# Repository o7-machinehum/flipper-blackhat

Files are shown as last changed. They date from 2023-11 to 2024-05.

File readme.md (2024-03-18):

# Flipper Blackhat
The Flipper Blackhat is a Flipper addon board that runs Linux. It is primarily used for WiFi testing and hacking.


## Other Resources
- [Operating System](https://github.com/o7-machinehum/flipper-blackhat-os)
- [App](https://github.com/o7-machinehum/flipper-blackhat-app)

## R1 Issues
- Reset button doesn't work
- Spacing between M.2 Connectors WRONG

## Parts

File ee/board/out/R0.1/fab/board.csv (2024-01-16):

Source: | /Users/machinehum/projects/flipper-blackhat/ee/board/board.kicad_sch
Date: | 2024 January 09, Tuesday 15:48:44
Tool: | Eeschema 7.0.7
Generator: | /opt/homebrew/bin/kicad-vault
Component Count: | 54
Ref | Qnty | Value | Footprint | Part Number | Detailed Description | QTD Available | Price (QTD 1) | Price (QTD 10) | Price (QTD 100) | Price (QTD 500) | Price (QTD 1000)
C1, C2, C3, C4, | 4 | 10uF | Capacitor_SMD:C_0603_1608Metric | LMK107BBJ106MALT | 10 µF ±20% 10V Ceramic Capacitor X5R 0603 (1608 Metric) | 3863423 | 0.18 | 0.124 | 0.0584 | 0.04312 | 0.0357
C8, C10, C11, C12, C16, | 5 | 100nF | Capacitor_SMD:C_0603_1608Metric | CC0603KRX7R7BB104 | 0.1 µF ±10% 16V Ceramic Capacitor X7R 0603 (1608 Metric) | 11594404 | 0.1 | 0.042 | 0.0185 | 0.01392 | 0.01094
C9, | 1 | 1nF | Capacitor_SMD:C_0603_1608Metric | CC0603KRX7R7BB102 | 1000 pF ±10% 16V Ceramic Capacitor X7R 0603 (1608 Metric) | 158845 | 0.1 | 0.041 | 0.0183 | 0.01378 | 0.01083
C13, C18, | 2 | 22nF | Capacitor_SMD:C_0603_1608Metric | CC0603KRX7R7BB223 | 0.022 µF ±10% 16V Ceramic Capacitor X7R 0603 (1608 Metric) | 46528 | 0.1 | 0.053 | 0.0237 | 0.01782 | 0.014
C14, C15, | 2 | 18pF | Capacitor_SMD:C_0603_1608Metric | CC0603JPNPO9BN180 | 18 pF ±5% 50V Ceramic Capacitor C0G, NP0 0603 (1608 Metric) | 25871 | 0.1 | 0.035 | 0.0156 | 0.01178 | 0.00925
H1, | 1 | M2.5 Spacer | KiLib:9774025151R | 9774025151R | Round Standoff Threaded M2.5x0.45 Steel 0.098" (2.50mm) | 16948 | 1.27 | 1.217 | 0.979 | 0.01178 | 0.00925
J1, | 1 | Lichee_RV_J3 | KiLib:CONN75_2199230-3 | 2199230-3 | 67 Position Female Connector M.2 (NGFF) Mini Card Gold 0.020" (0.50mm) Black | 10721 | 1.61 | 1.47 | 1.3108 | 1.1732 | 0.00925
J2, | 1 | Lichee_RV_J4 | KiLib:CONN75_2199230-3 | 2199230-3 | 67 Position Female Connector M.2 (NGFF) Mini Card Gold 0.020" (0.50mm) Black | 10721 | 1.61 | 1.47 | 1.3108 | 1.1732 | 0.00925
J3, | 1 | USB_A | Connector_USB:USB_A_Receptacle_GCT_USB1046 | USB1046-GF-0190-L-B-A | USB-A (USB TYPE-A) USB 2.0 Receptacle Connector 4 Position Surface Mount, Through Hole | 0 | 1.61 | 1.47 | 1.3108 | 1.1732 | 0.00925
J4, | 1 | Conn_01x08_Pin | Connector_PinHeader_2.54mm:PinHeader_1x08_P2.54mm_Horizontal | PH1RB-08-UA | Connector Header Through Hole, Right Angle 8 position 0.100" (2.54mm) | 10117 | 0.23 | 0.196 | 0.1505 | 0.12738 | 0.10423
J5, | 1 | Conn_01x10_Pin | Connector_PinHeader_2.54mm:PinHeader_1x10_P2.54mm_Horizontal | PH1RB-10-UA | Connector Header Through Hole, Right Angle 10 position 0.100" (2.54mm) | 3117 | 0.24 | 0.202 | 0.1552 | 0.13132 | 0.10744
J6, | 1 | Conn_Coaxial | Connector_Coaxial:SMA_Amphenol_901-143_Horizontal | 901-143-6RFX | SMA Connector Jack, Female Socket 50 Ohms Through Hole, Right Angle Solder | 7948 | 9.33 | 8.397 | 7.5044 | 6.28748 | 5.55732
J8, | 1 | HR911105A | KiLib:HR911105a | HR911105A
L2, | 1 | 120R@100MHz | Inductor_SMD:L_0805_2012Metric | MMZ2012R121AT000 | 120 Ohms @ 100 MHz 1 Signal Line Ferrite Bead 0805 (2012 Metric) 800mA 120mOhm | 269595 | 0.1 | 0.081 | 0.0461 | 0.0307 | 0.02586
R1, R2, | 2 | 22R | Resistor_SMD:R_0603_1608Metric | RC0603FR-1322RL | 22 Ohms ±1% 0.1W, 1/10W Chip Resistor 0603 (1608 Metric) Moisture Resistant Thick Film | 139305 | 0.1 | 0.019 | 0.0093 | 0.00622 | 0.00532
R3, | 1 | 0R | Resistor_SMD:R_0603_1608Metric | RC0603FR-130RL | 0 Ohms Jumper Chip Resistor 0603 (1608 Metric) Moisture Resistant Thick Film | 24216 | 0.1 | 0.017 | 0.007 | 0.00448 | 0.00329
R5, R6, R7, R8, R9, R10, R11, R21, R30, R32, R33, | 11 | 5.1k | Resistor_SMD:R_0603_1608Metric | RC0603FR-135K1L | 5.1 kOhms ±1% 0.1W, 1/10W Chip Resistor 0603 (1608 Metric) Thick Film | 155768 | 0.1 | 0.019 | 0.0093 | 0.00622 | 0.00532
R13, | 1 | 10k | Resistor_SMD:R_0603_1608Metric | RC0603FR-1310KL | 10 kOhms ±1% 0.1W, 1/10W Chip Resistor 0603 (1608 Metric) Moisture Resistant Thick Film | 152935 | 0.1 | 0.019 | 0.0093 | 0.00622 | 0.00532
R15, | 1 | 100K | Resistor_SMD:R_0603_1608Metric | RC0603FR-13100KL | 100 kOhms ±1% 0.1W, 1/10W Chip Resistor 0603 (1608 Metric) Moisture Resistant Thick Film | 44445 | 0.1 | 0.019 | 0.0093 | 0.00622 | 0.00532
R16, R17, | 2 | 1k | Resistor_SMD:R_0603_1608Metric | RC0603FR-131KL | 1 kOhms ±1% 0.1W, 1/10W Chip Resistor 0603 (1608 Metric) Moisture Resistant Thick Film | 49915 | 0.1 | 0.019 | 0.0093 | 0.00622 | 0.00532
R19, | 1 | 100R | Resistor_SMD:R_0603_1608Metric | RC0603FR-13100KL | 100 kOhms ±1% 0.1W, 1/10W Chip Resistor 0603 (1608 Metric) Moisture Resistant Thick Film | 44445 | 0.1 | 0.019 | 0.0093 | 0.00622 | 0.00532
R31, R34, | 2 | 470R | Resistor_SMD:R_0603_1608Metric | RC0603FR-13470KL | 470 kOhms ±1% 0.1W, 1/10W Chip Resistor 0603 (1608 Metric) Moisture Resistant Thick Film | 80619 | 0.1 | 0.019 | 0.0093 | 0.00622 | 0.00532
RN1, RN2, | 2 | 10k | Resistor_SMD:R_Array_Convex_4x0402 | 4D02WGJ0103TCE
RN5, RN6, RN7, | 3 | 22R | Resistor_SMD:R_Array_Convex_4x0402 | 4D02WGJ0220TCE
SW1, | 1 | SW_Push | Button_Switch_SMD:SW_SPST_PTS645 | PTS645SH43SMTR92 LFS | Tactile Switch SPST-NO Top Actuated Surface Mount | 280362 | 0.28 | 0.275 | 0.2364 | 0.20032 | 0.00532
U1, | 1 | RTL8201F | Package_DFN_QFN:QFN-32-1EP_5x5mm_P0.5mm_EP3.3x3.3mm | RTL8201F
U2, | 1 | RTL8723DS | KiLib:RTL8723 | RTL8723DS
U6, | 1 | USBLC6-2SC6 | Package_TO_SOT_SMD:SOT-23-6 | USBLC6-2SC6 | 17V Clamp 5A (8/20µs) Ipp Tvs Diode Surface Mount SOT-23-6 | 69609 | 0.58 | 0.496 | 0.3448 | 0.2692 | 0.21881
Y1, | 1 | Crystal_GND24_Small | Crystal:Crystal_SMD_3225-4Pin_3.2x2.5mm | 7M25000033

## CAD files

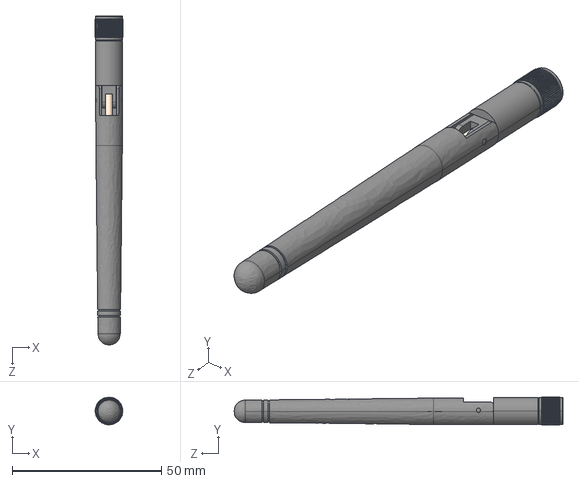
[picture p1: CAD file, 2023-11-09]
ee/board/step/antenna.step
9.33 x 9.33 x 110.2 mm

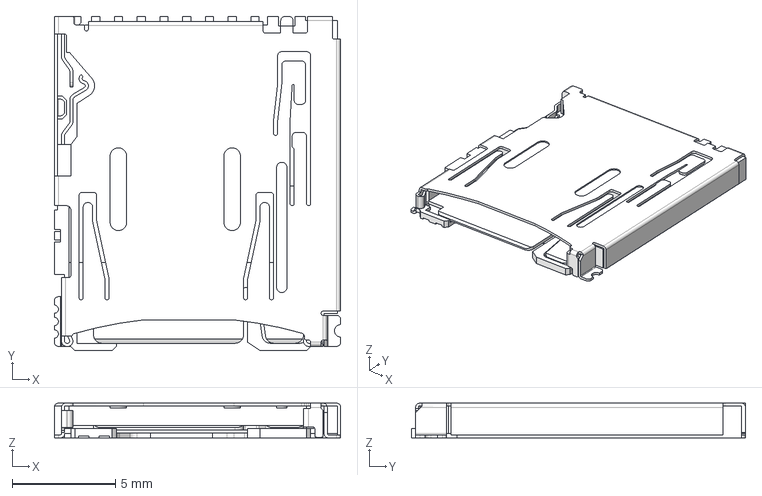
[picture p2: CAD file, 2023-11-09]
ee/board/step/DM3AT-SF-PEJM5.stp
13.8 x 16.2 x 1.68 mm

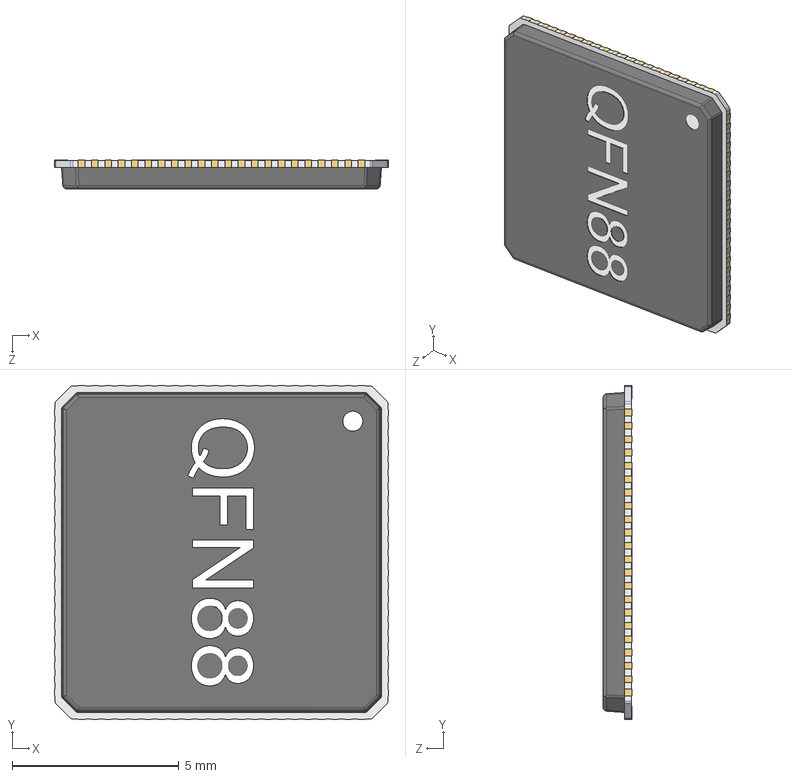
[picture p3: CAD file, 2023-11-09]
ee/board/step/QFN88.stp
10.0 x 10.0 x 0.87 mm

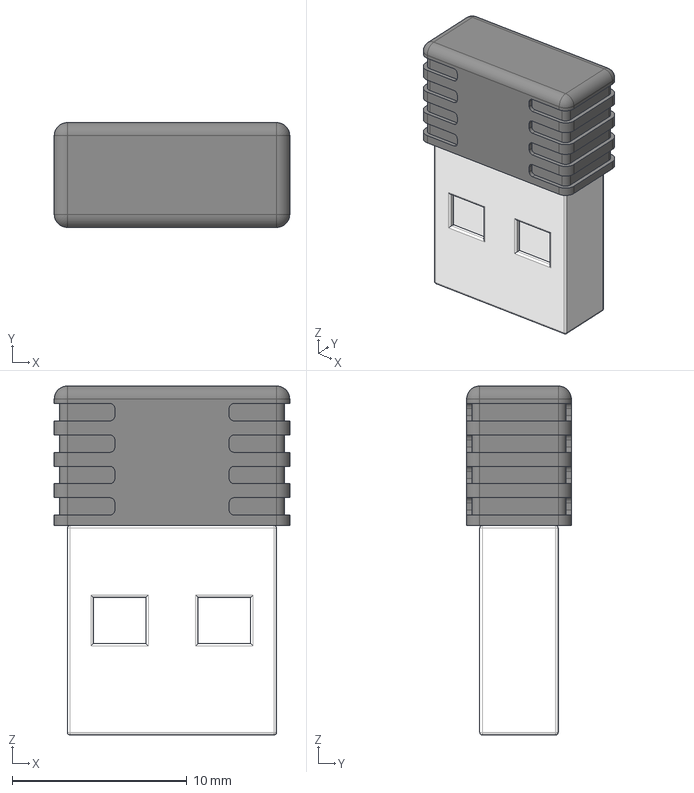
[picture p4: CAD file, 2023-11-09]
ee/board/step/mini_usb_wifi_adapter.stp
13.5 x 6.00 x 20.0 mm

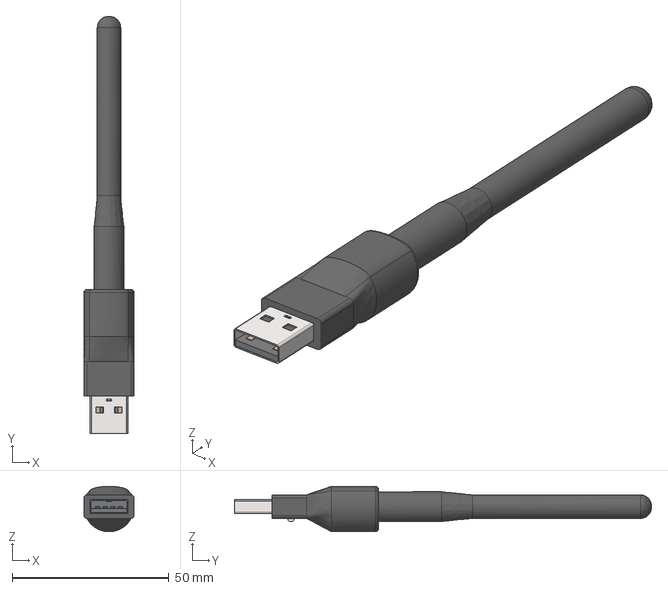
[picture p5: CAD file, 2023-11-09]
ee/board/step/usb-antenna.step
16.0 x 132.9 x 14.5 mm

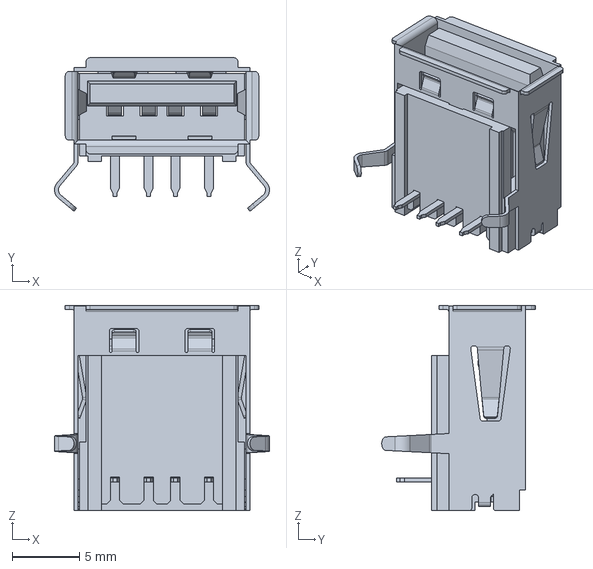
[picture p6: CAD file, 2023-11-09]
ee/board/step/676432911.stp
16.0 x 11.4 x 15.3 mm

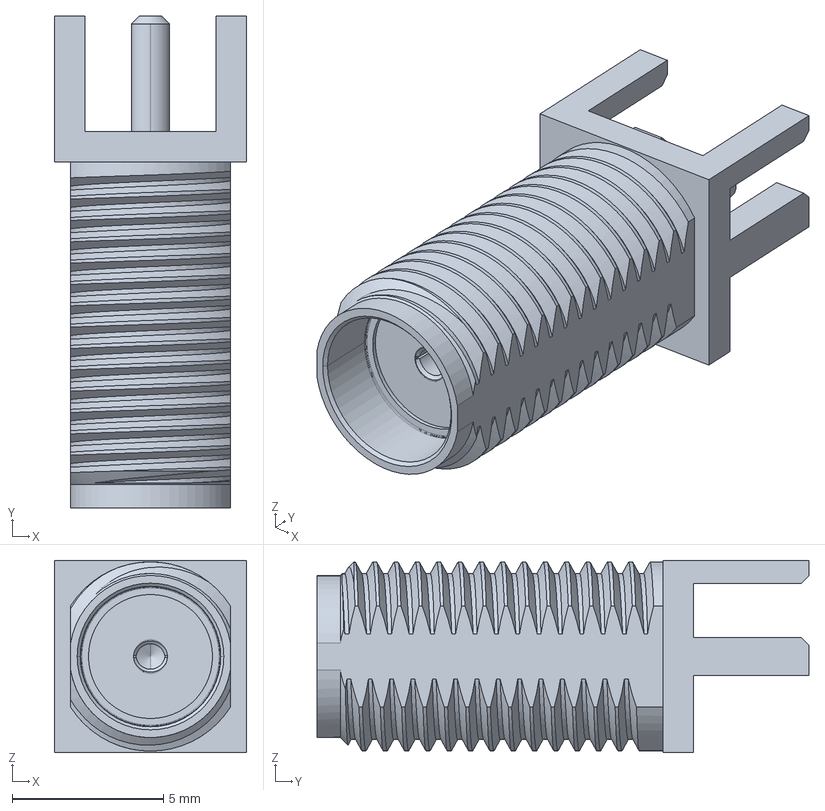
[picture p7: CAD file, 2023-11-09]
ee/board/step/732512120.stp
6.35 x 16.3 x 6.35 mm

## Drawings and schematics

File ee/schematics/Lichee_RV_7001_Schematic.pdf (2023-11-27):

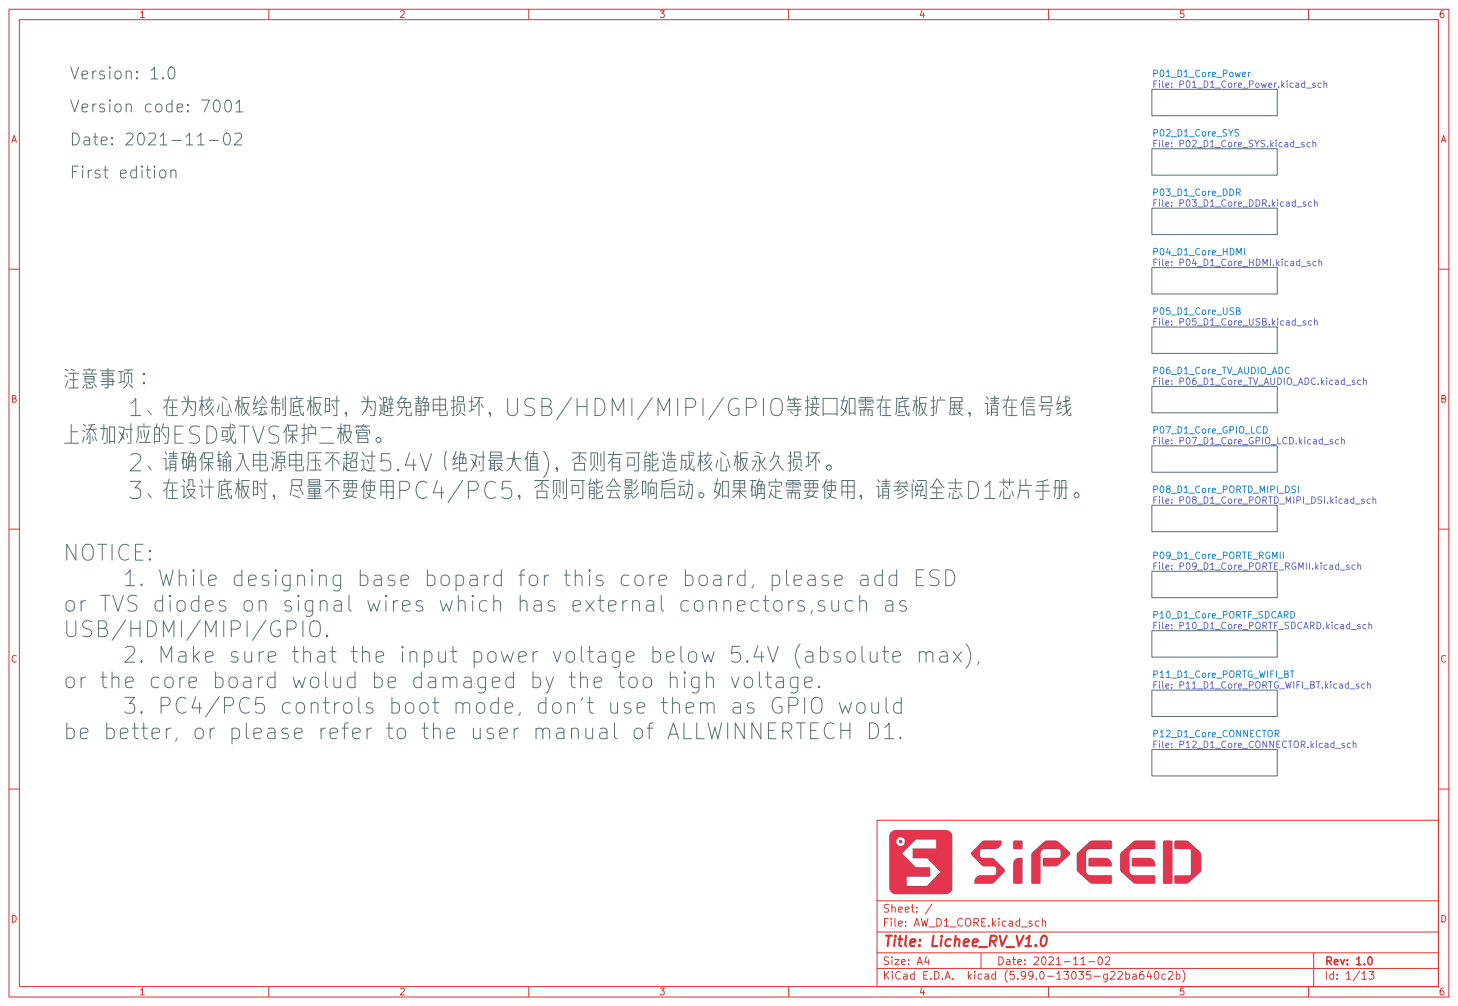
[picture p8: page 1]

þÿlèaN‹˜yÿ
þÿ 10W(N:h8_Ãg•~ØR6^•g•eöÿN:••QM—Yu5c_WOÿUSB/HDMI/MIPI/GPIO{Ic¥SãY‚—W(^•g•bi\Uÿ‹÷W(OáS÷~¿
þÿN
þÿ 20‹÷xnOÝ•“Qeu5n•u5S‹N
þÿ 30W(‹¾‹¡^•g•eöÿ\=‘ÏN

mûR [ù^”v„ESDbTVSOÝb¤NŒg•{¡0-

File: P12_D1_Core_CONNECTOR.kicad_sch NOTICE:
1. While designing base bopard for this core board, please add ESD
or TVS diodes on signal wires which has external connectors,such as
USB/HDMI/MIPI/GPIO.
2. Make sure that the input power voltage below 5.4V (absolute max),
or the core board wolud be damaged by the too high voltage.
3. PC4/PC5 controls boot mode, don't use them as GPIO would
be better, or please refer to the user manual of ALLWINNERTECH D1.

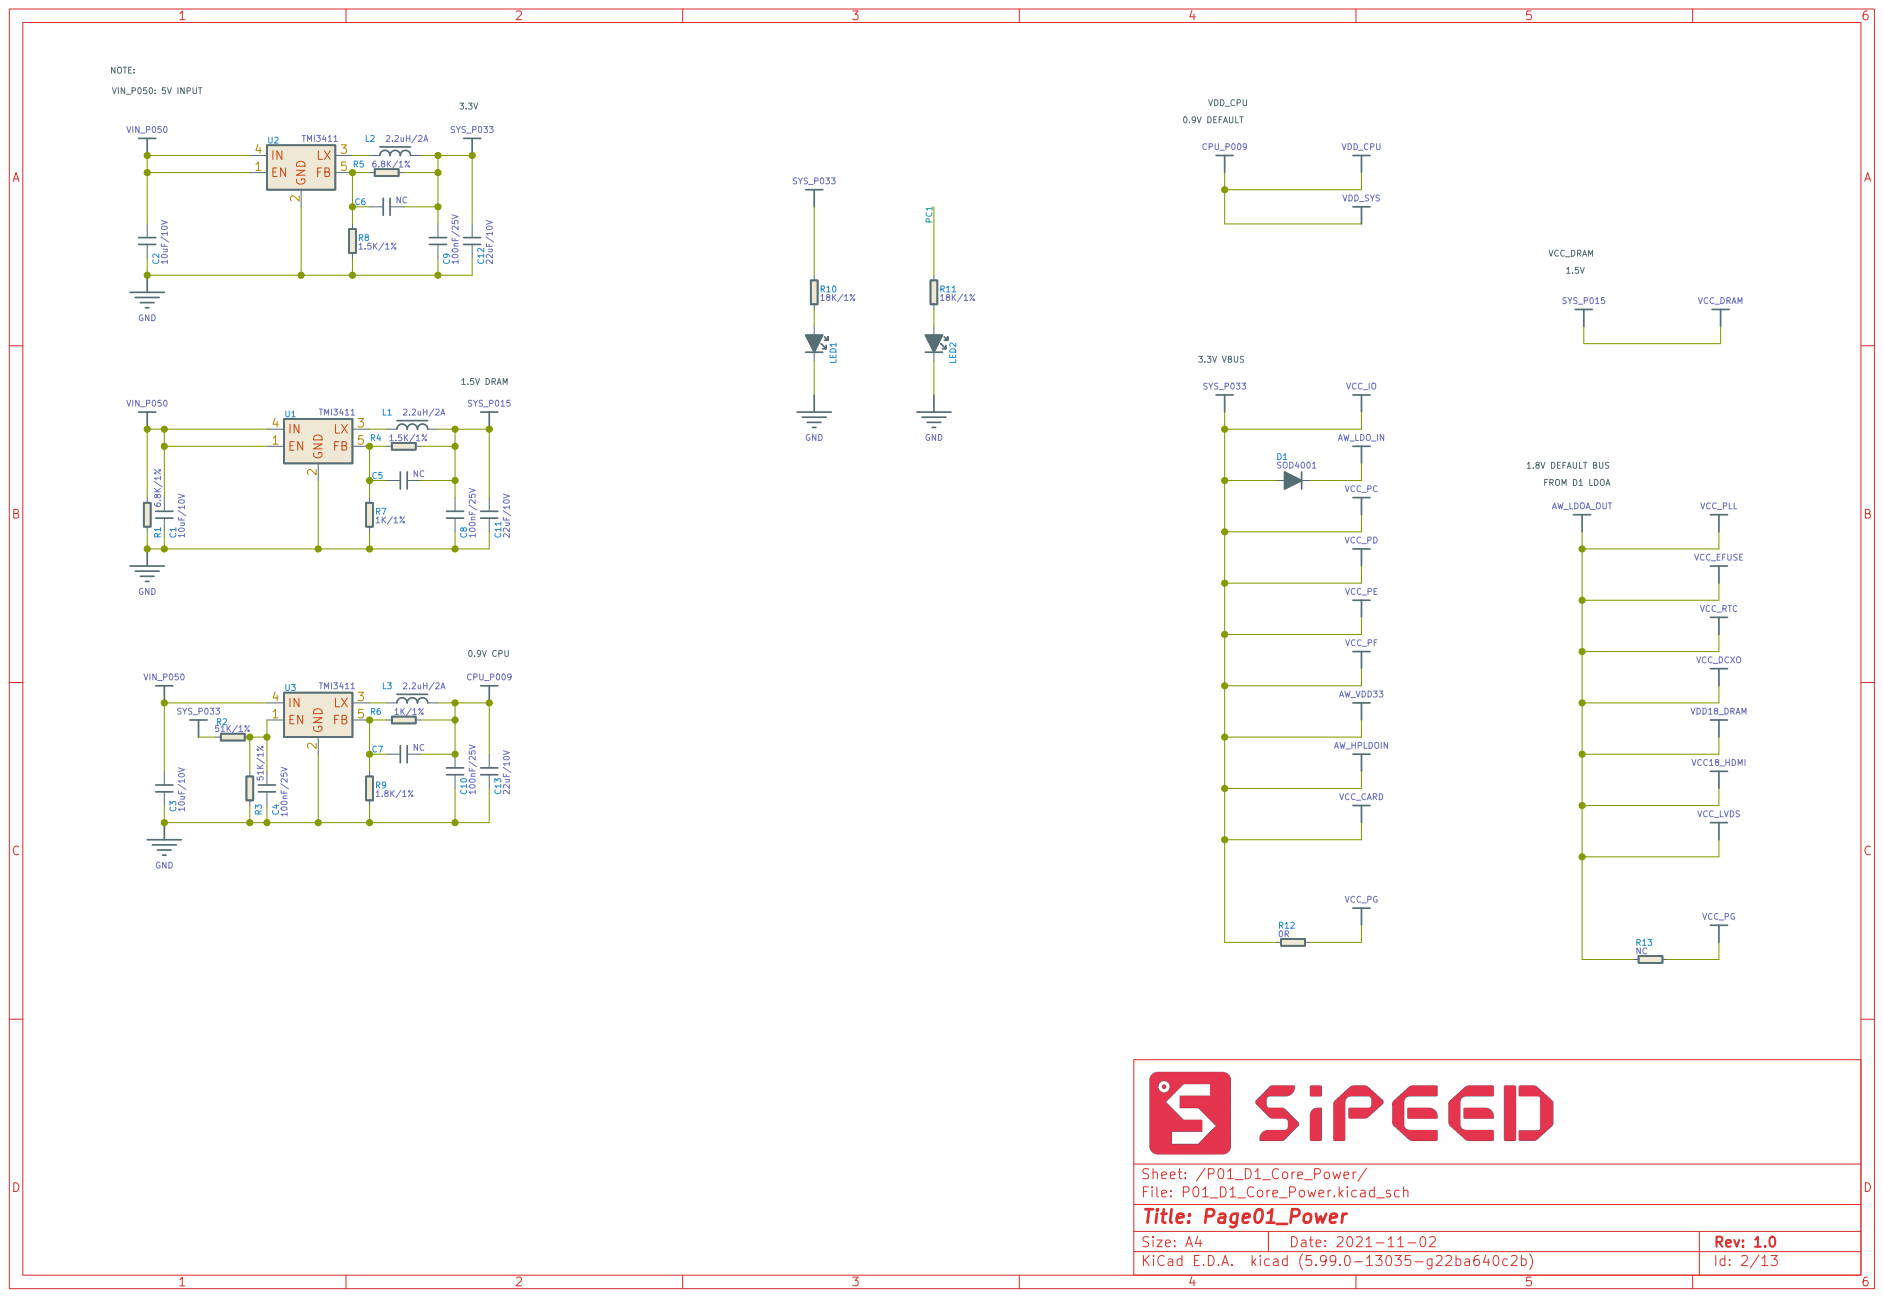
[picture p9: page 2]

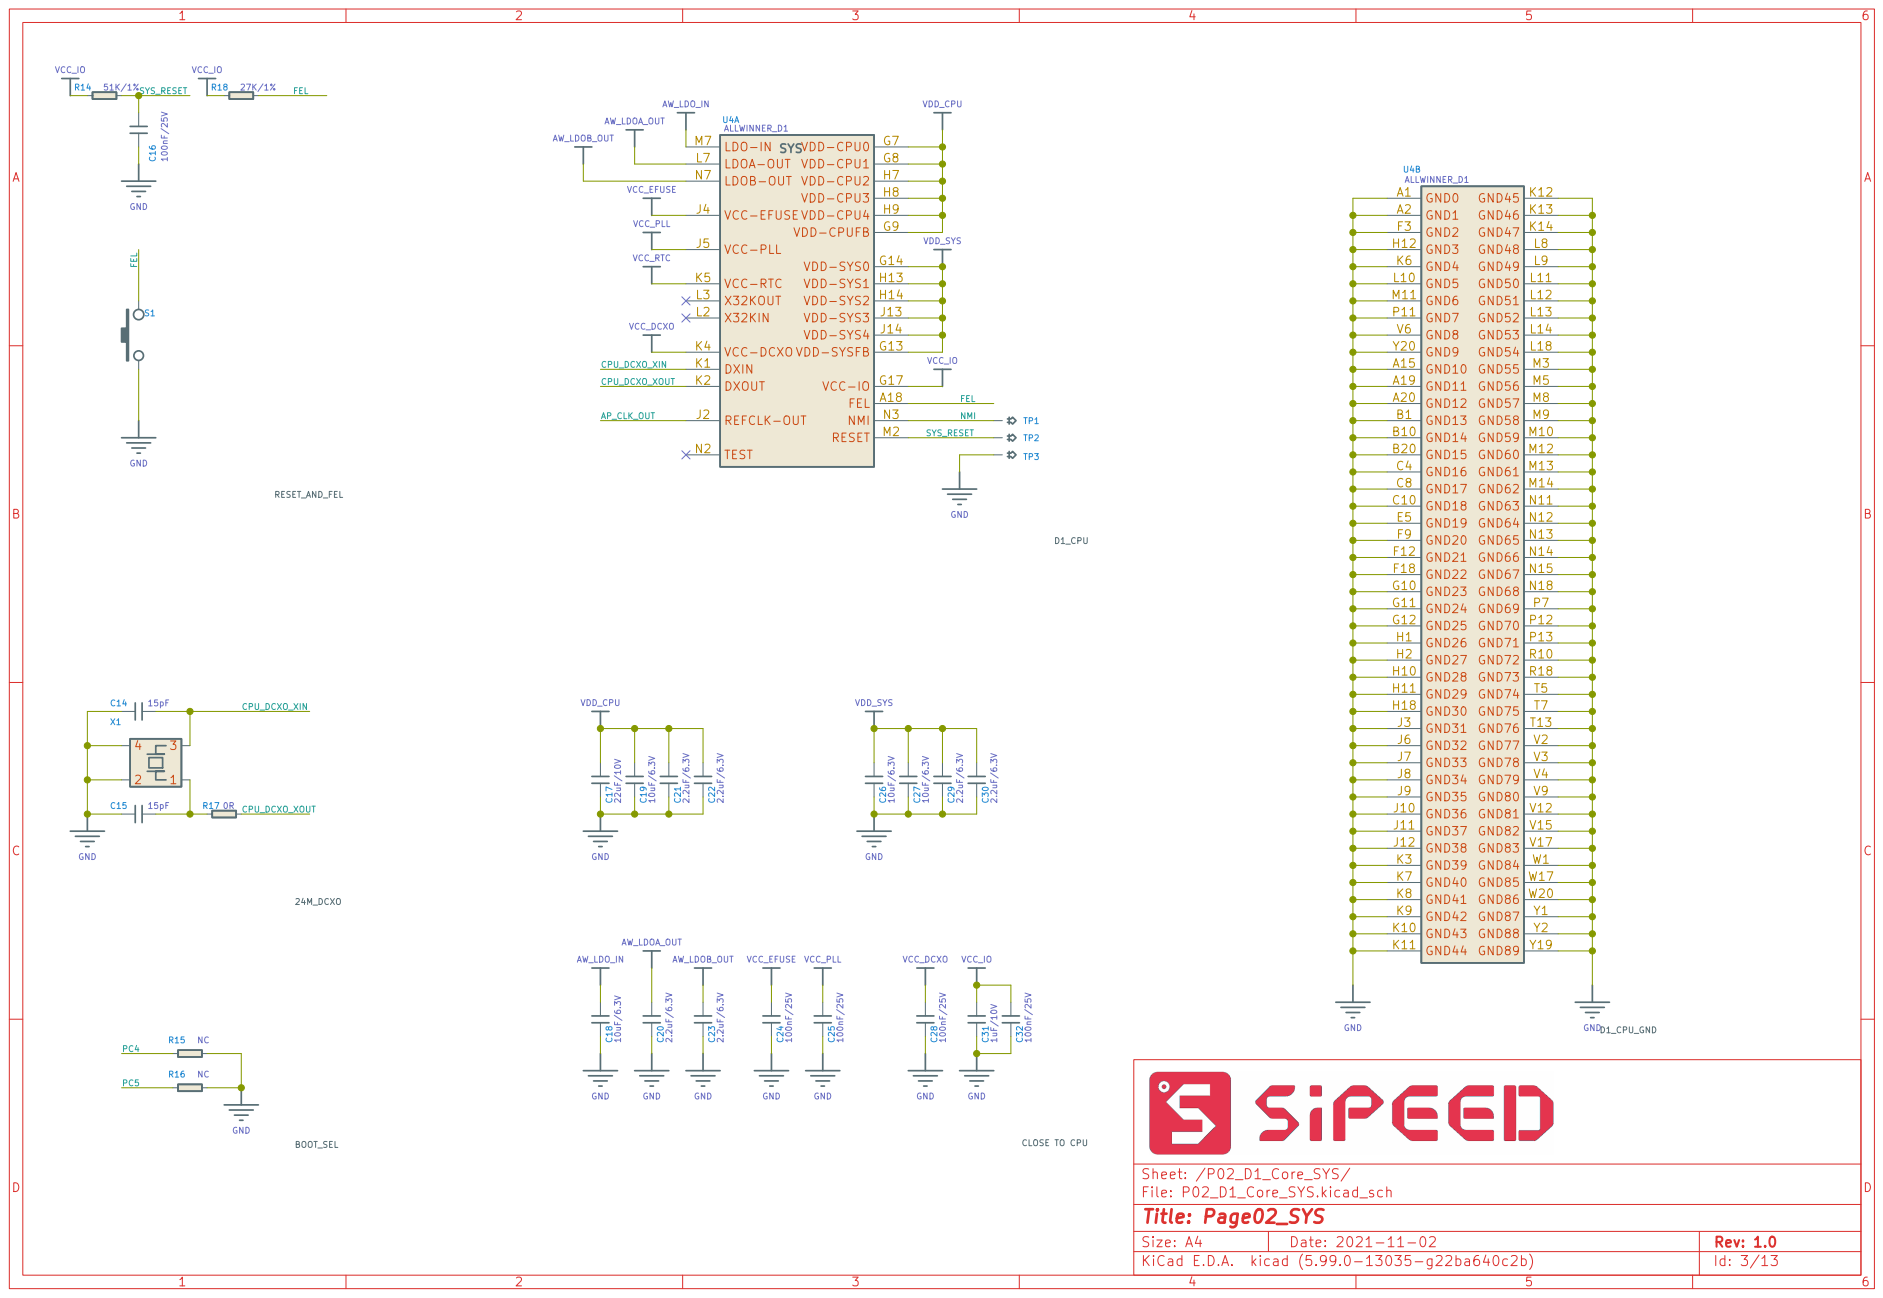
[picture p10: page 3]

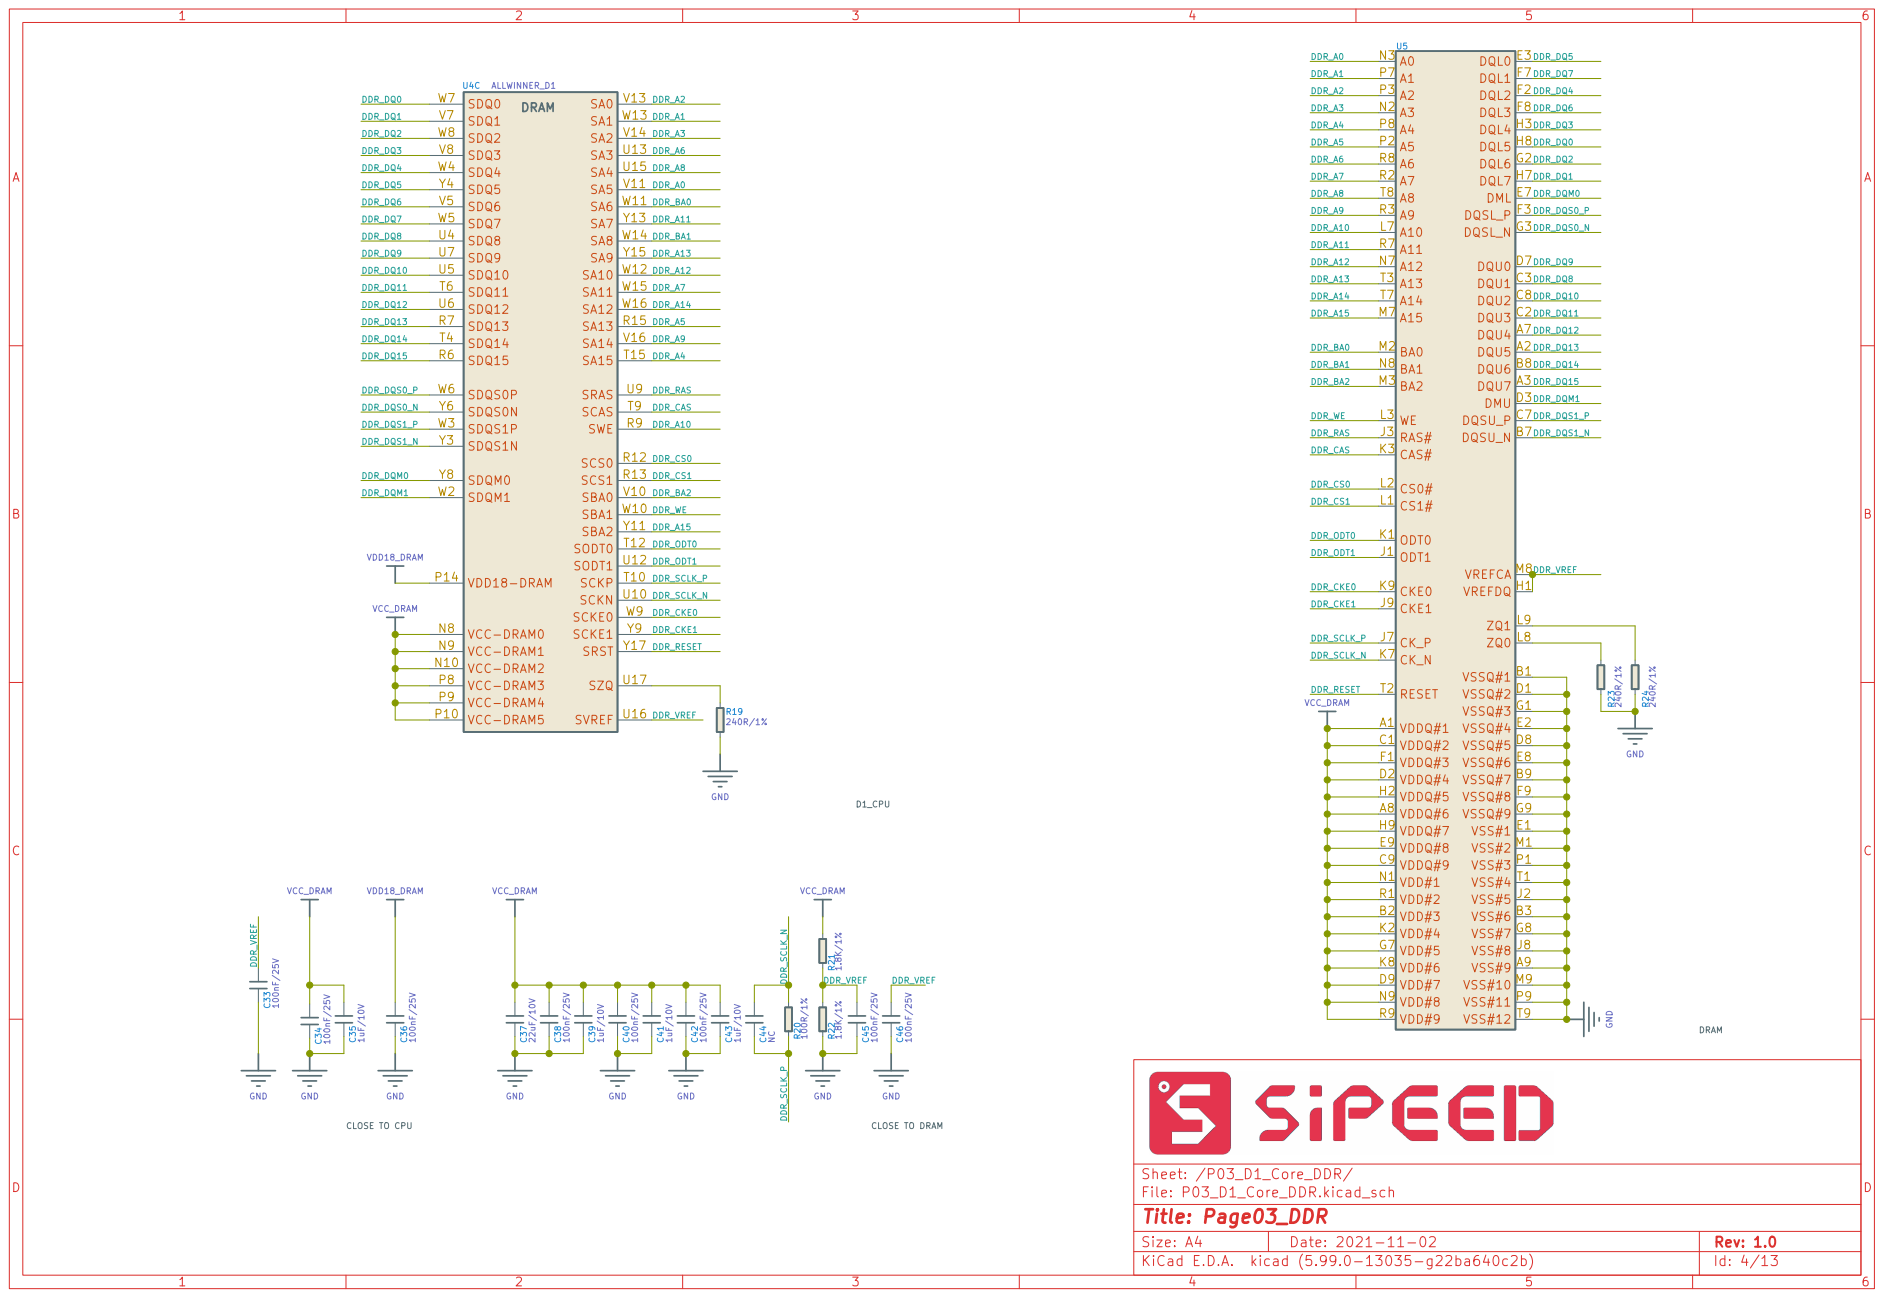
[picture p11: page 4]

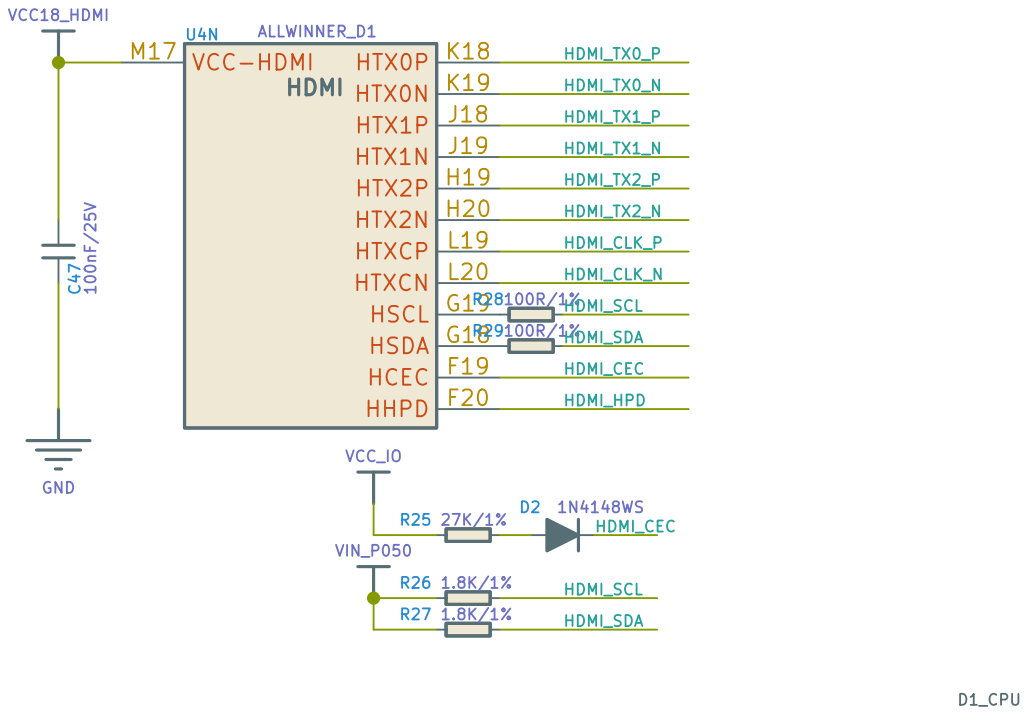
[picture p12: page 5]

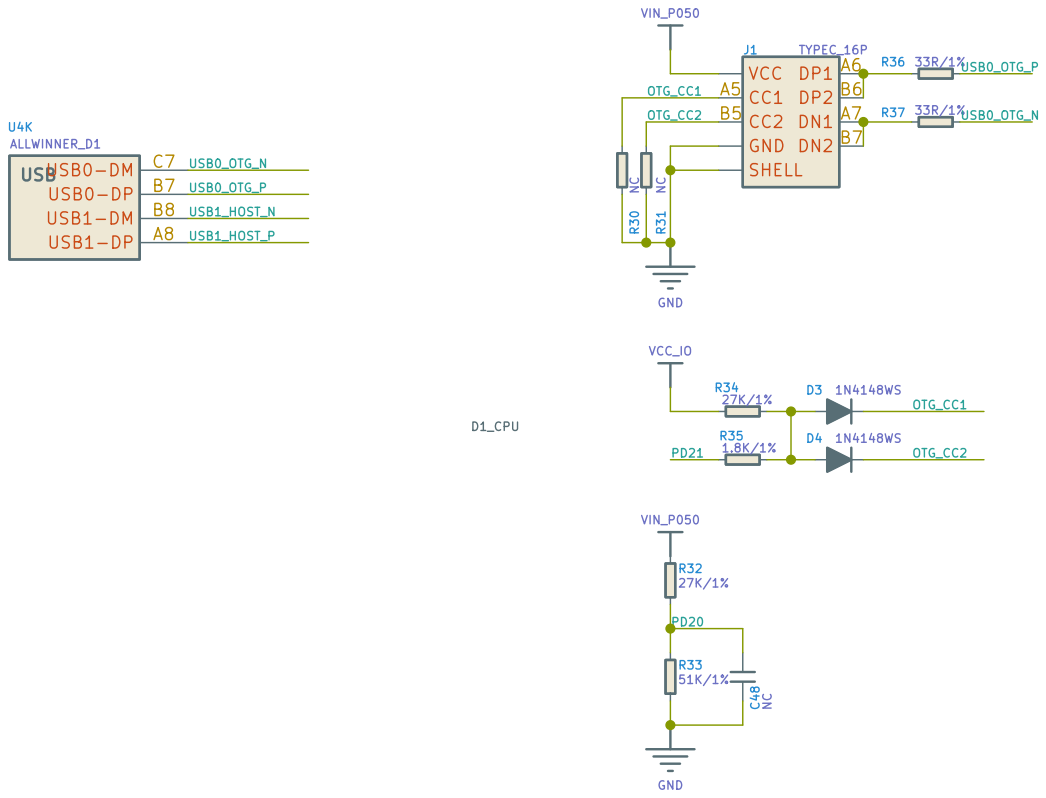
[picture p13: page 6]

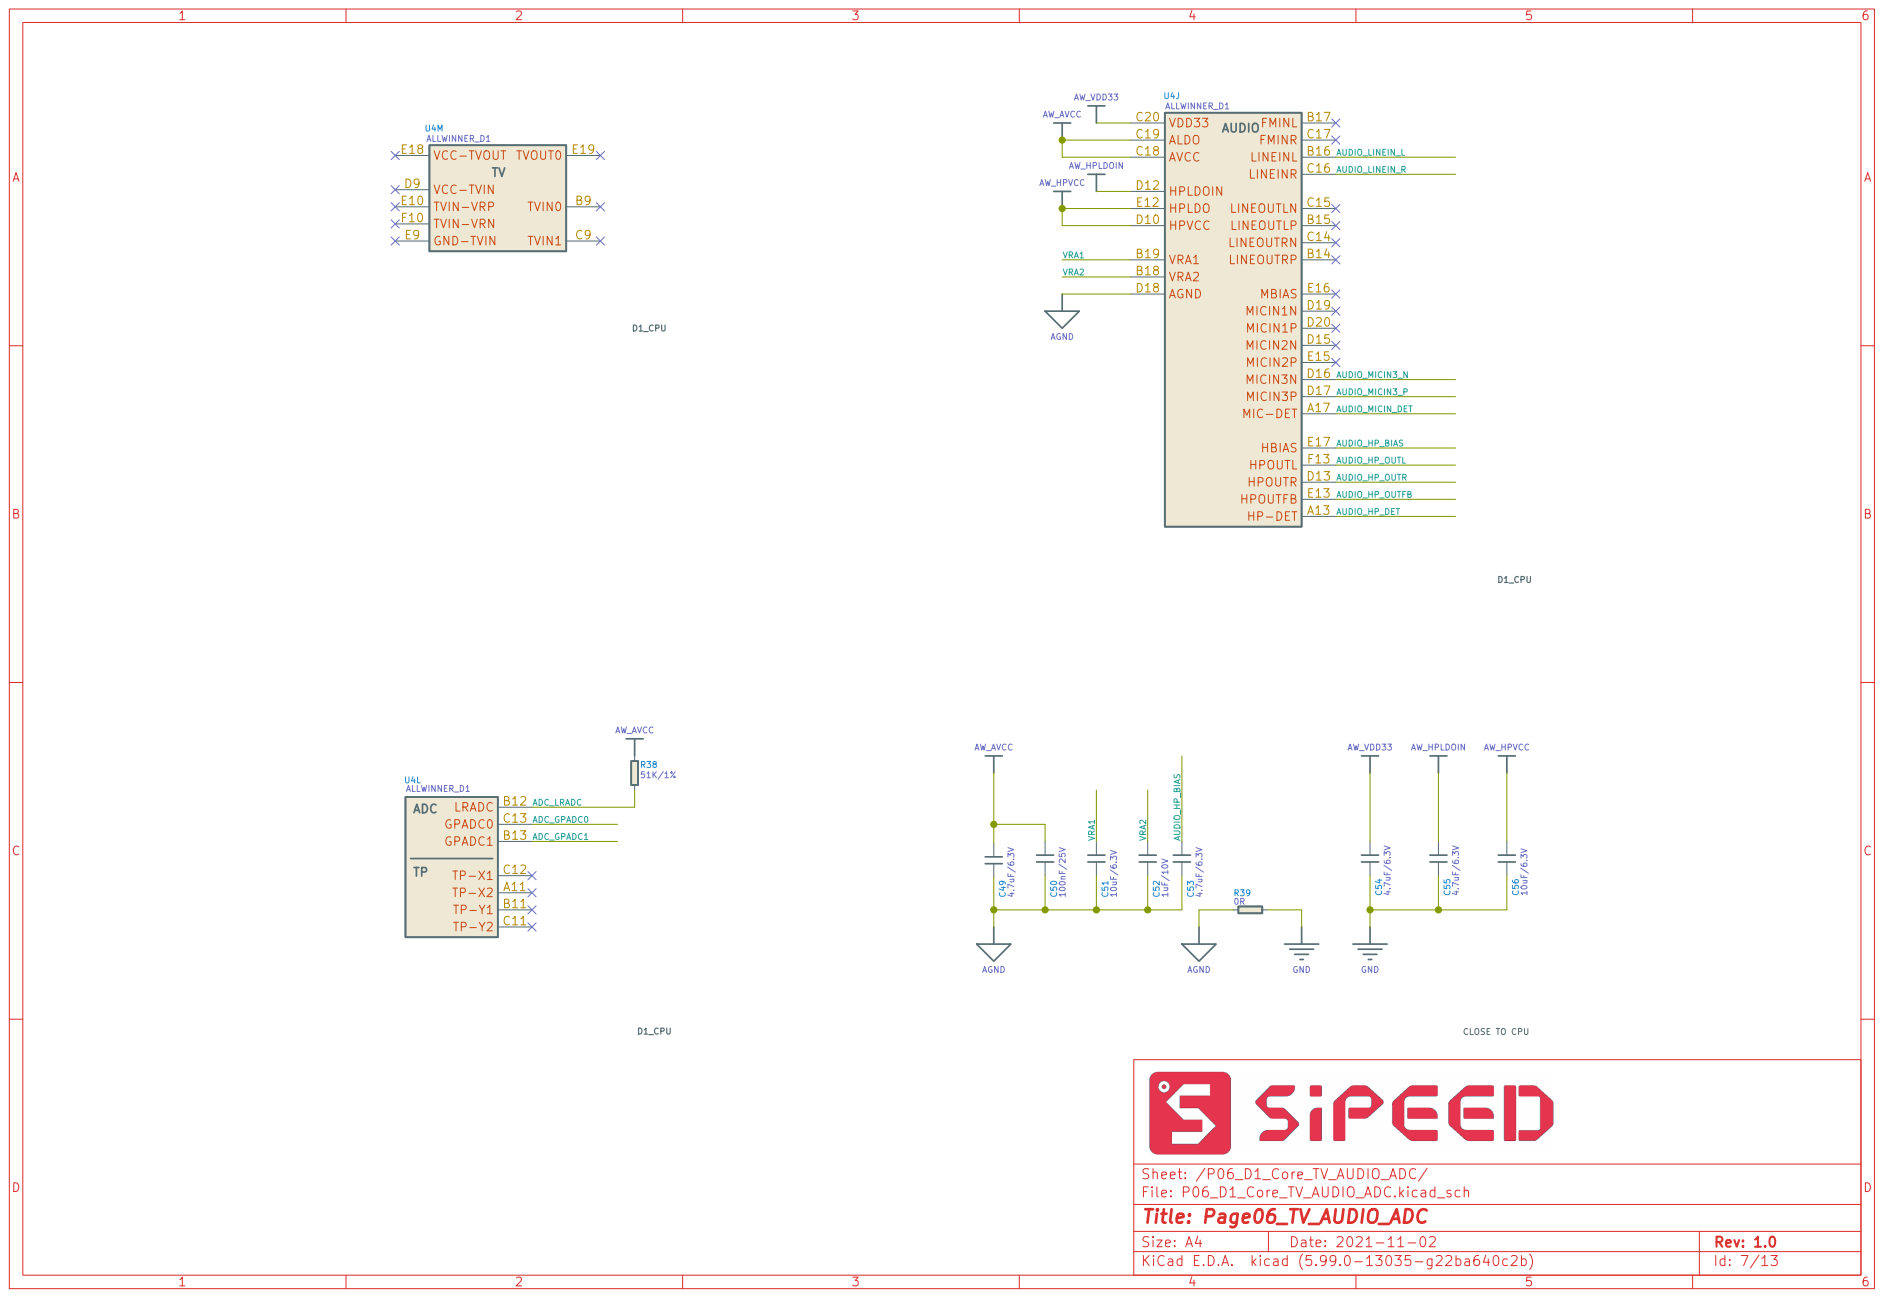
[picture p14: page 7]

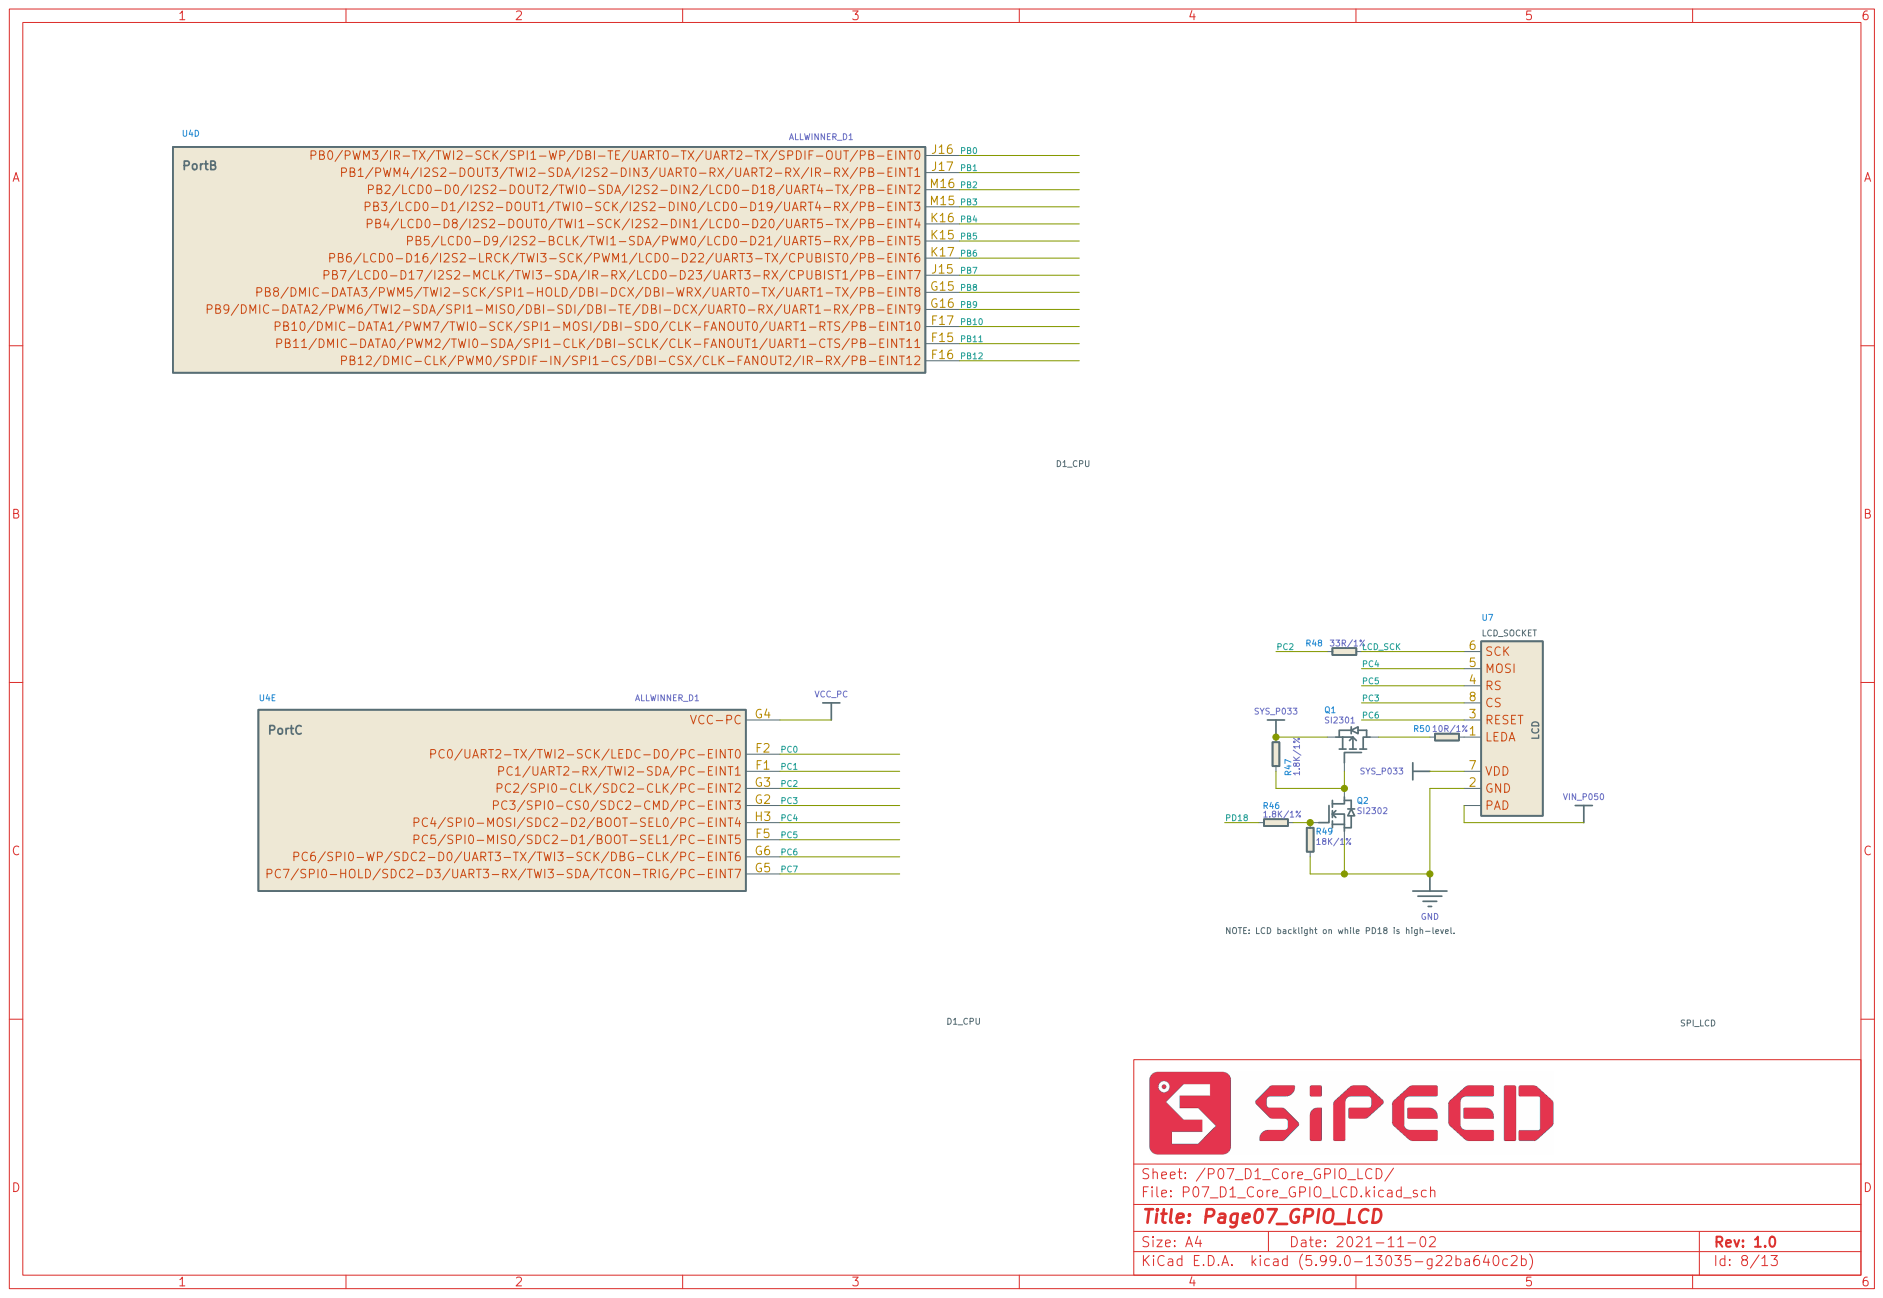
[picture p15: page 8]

NOTE: LCD backlight on while PD18 is high-level.

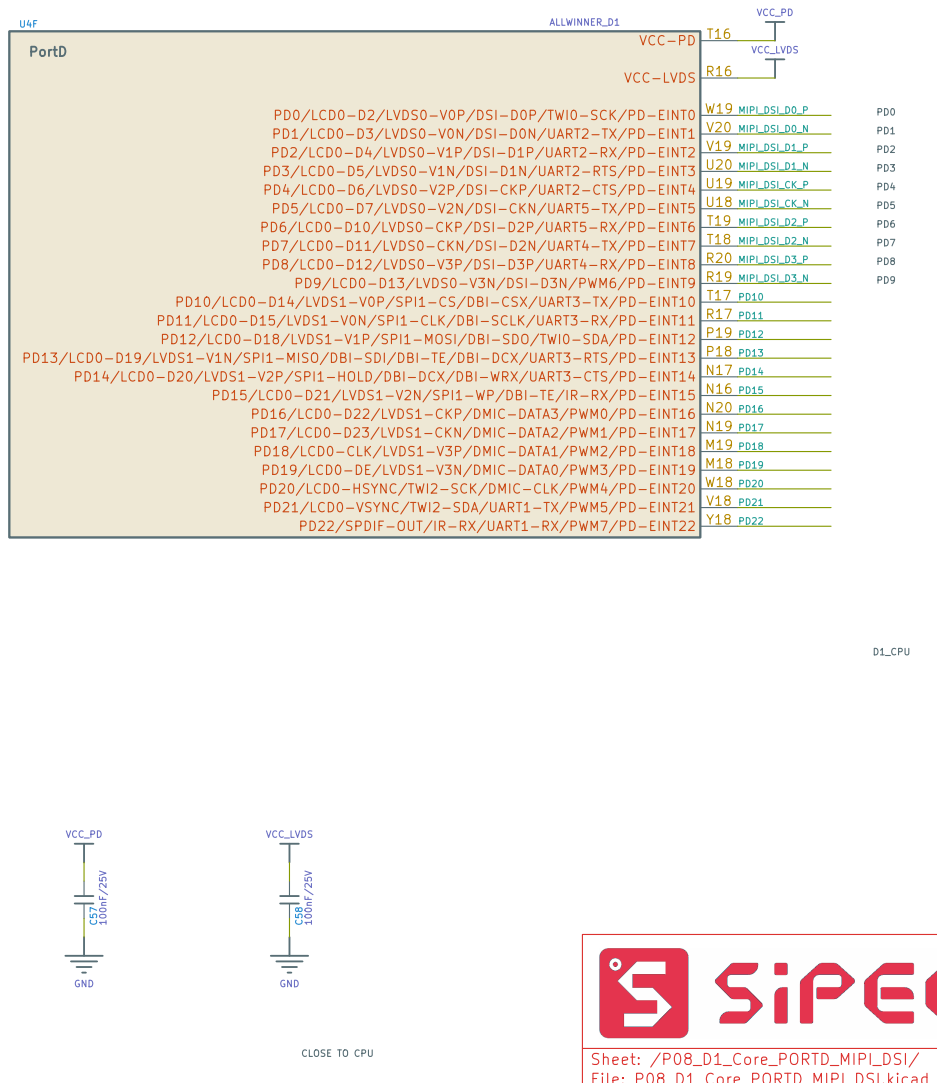
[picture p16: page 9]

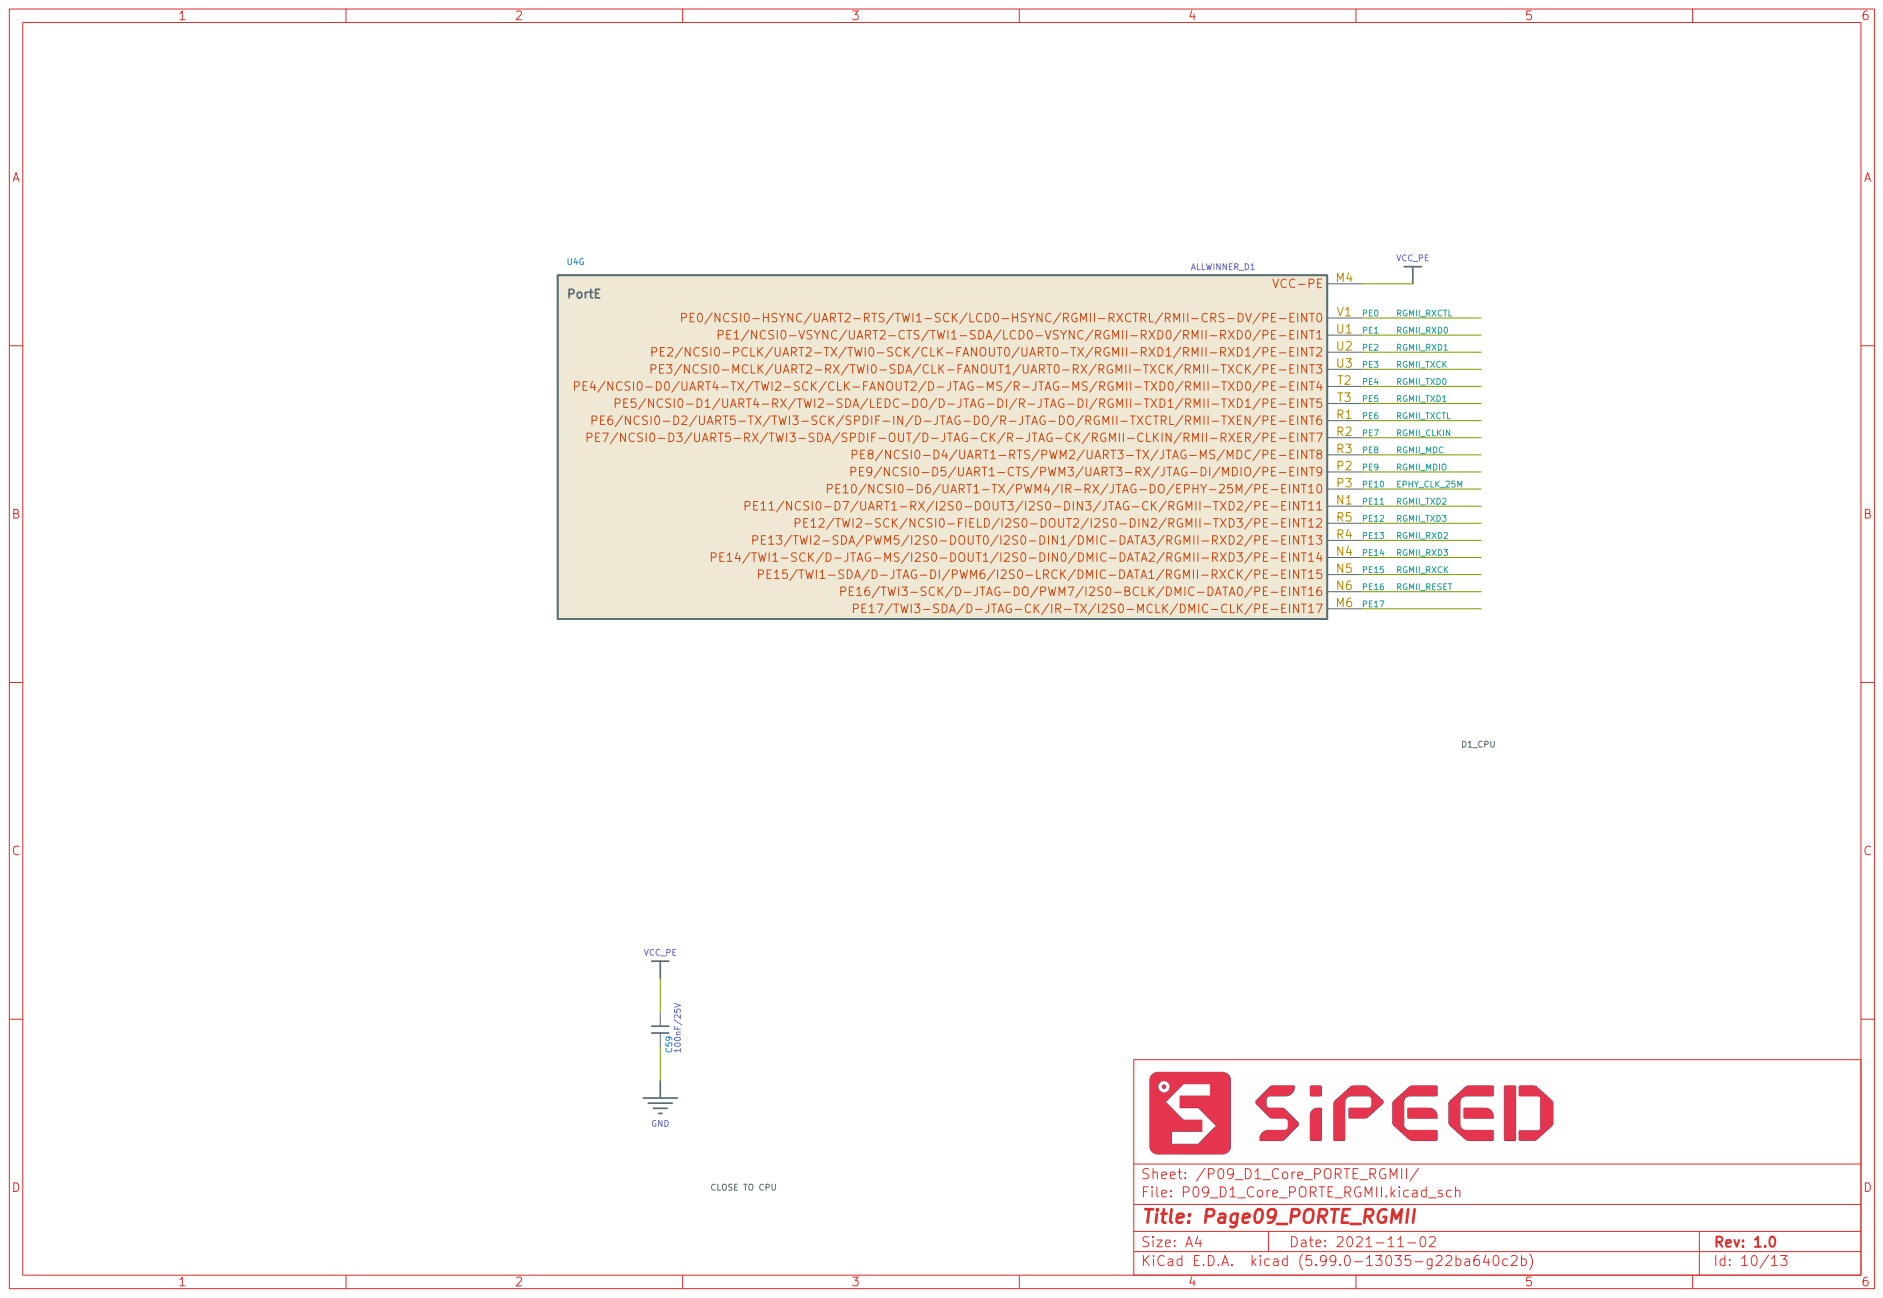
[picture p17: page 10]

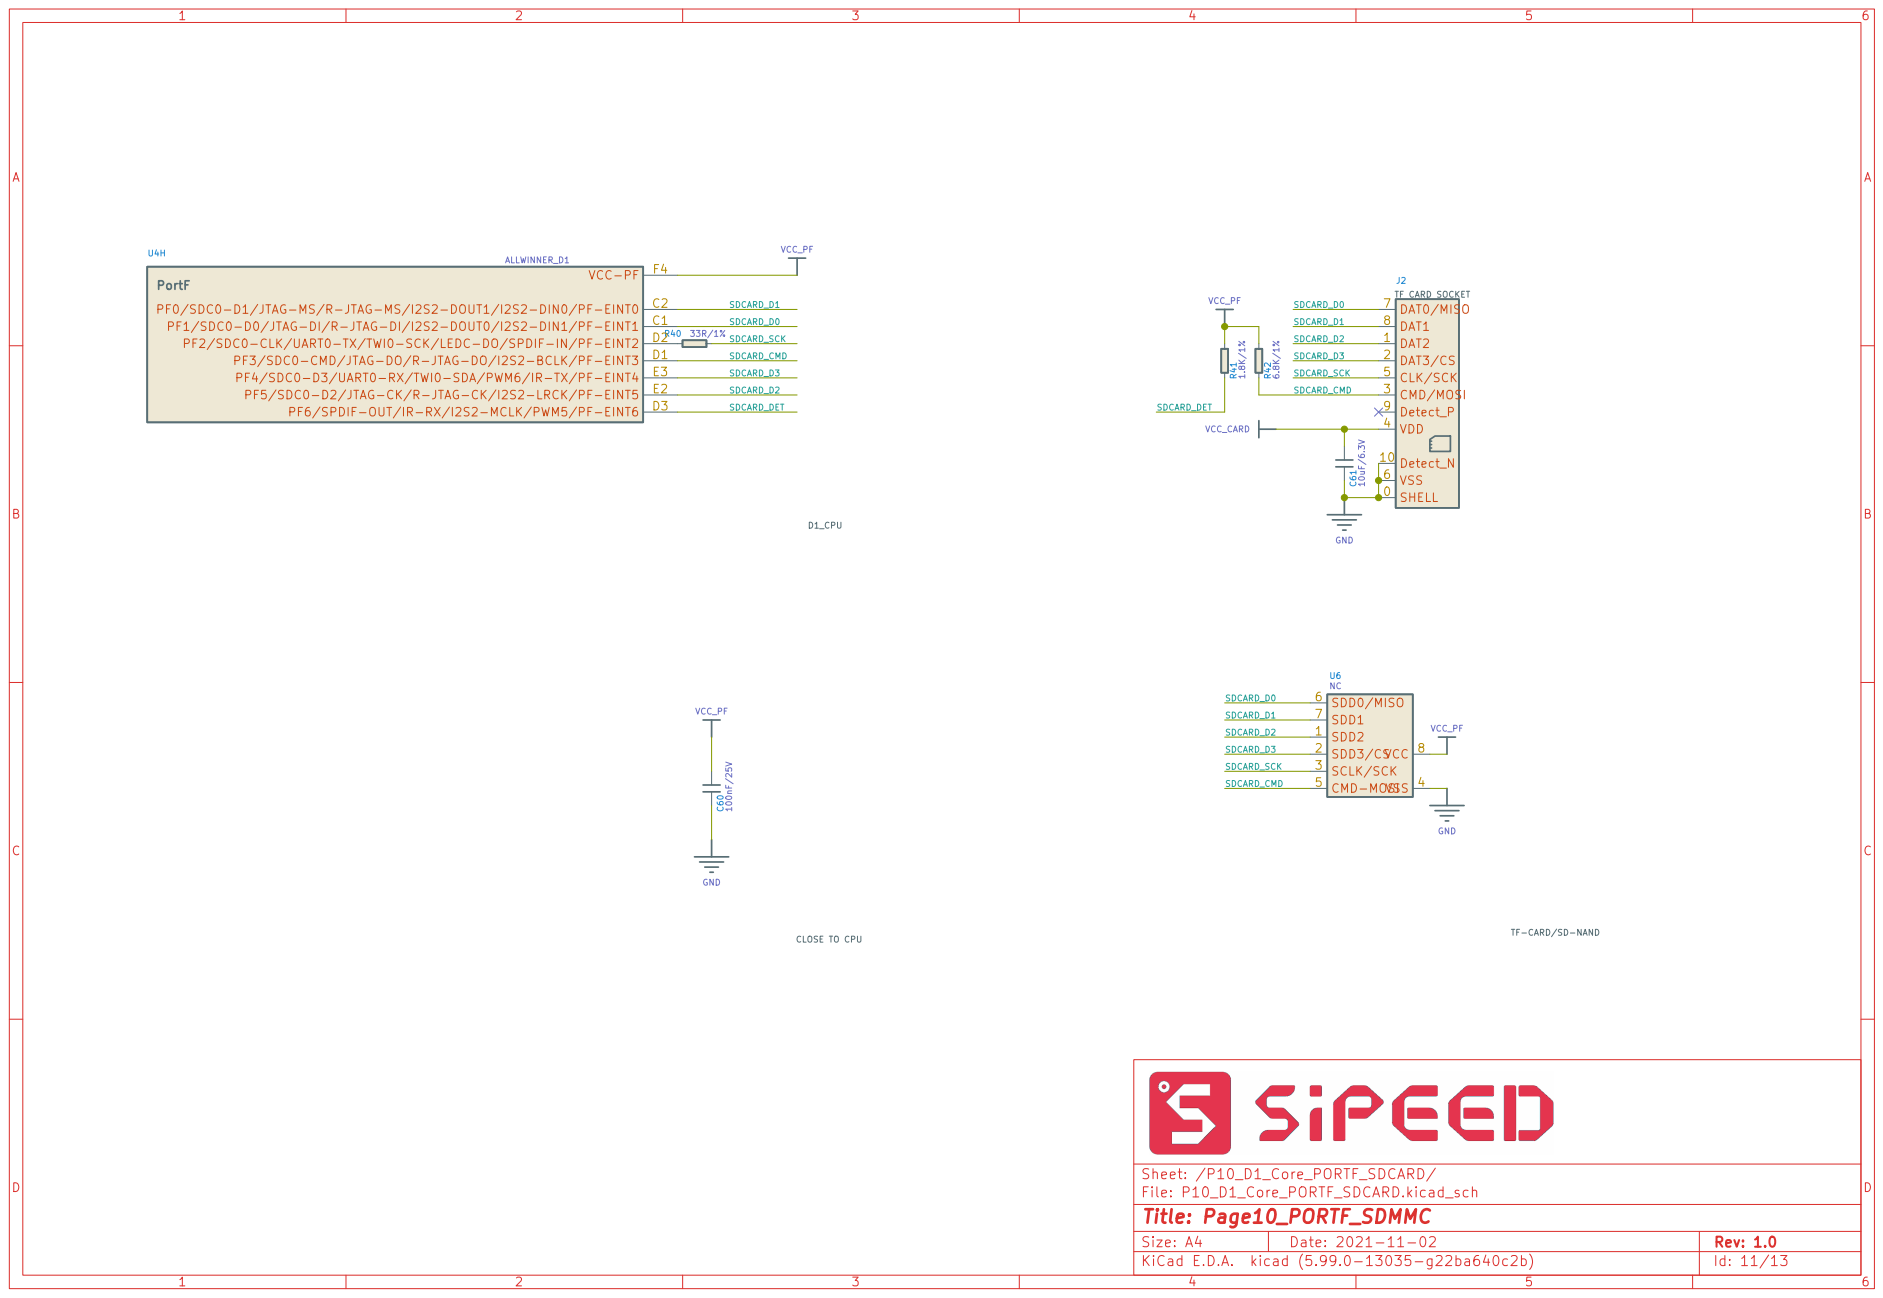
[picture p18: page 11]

TF-CARD/SD-NAND

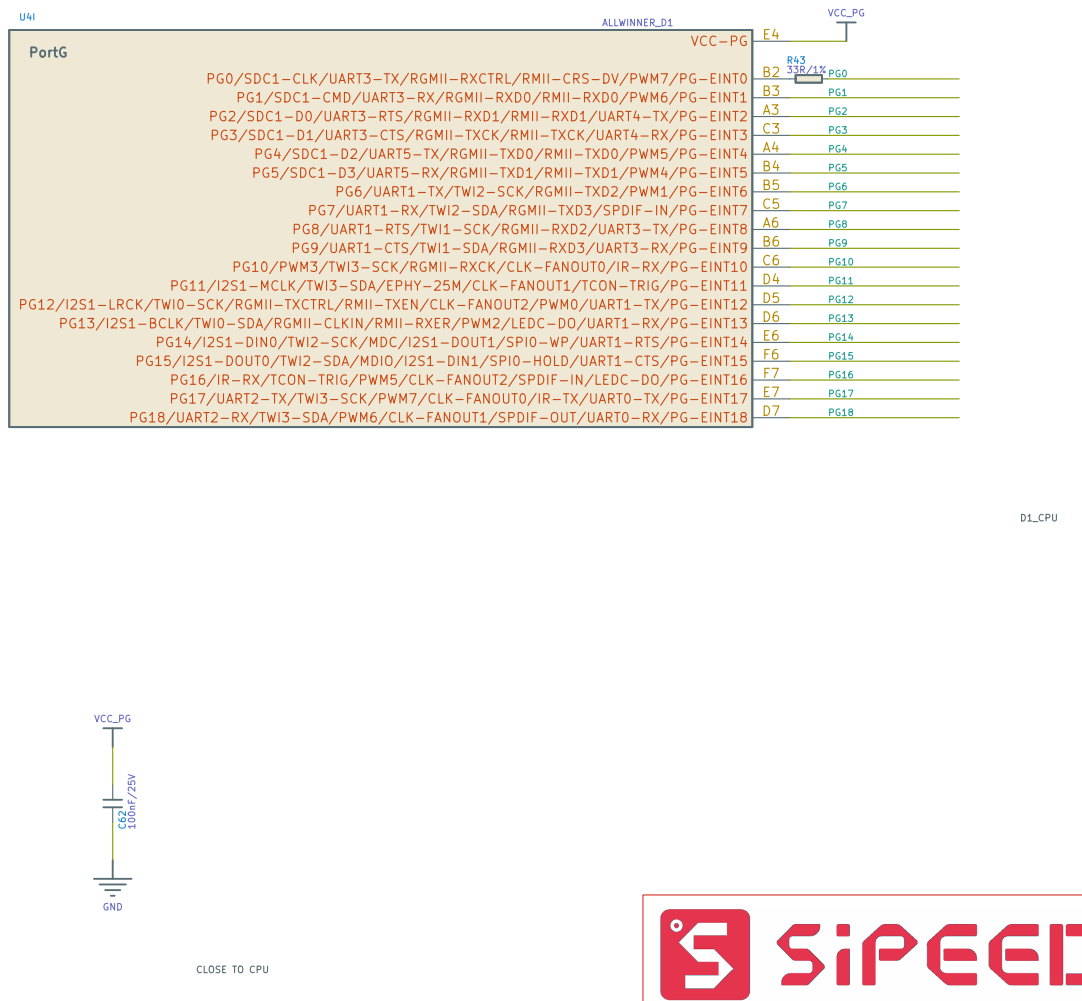
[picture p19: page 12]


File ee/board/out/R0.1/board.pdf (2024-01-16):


Id: 1/2 Title: Flipper Blackhat File: board.kicad_sch Sheet: /


Id: 2/2 Title: Flipper Blackhat File: ethernet.kicad_sch Sheet: /Ethernet/

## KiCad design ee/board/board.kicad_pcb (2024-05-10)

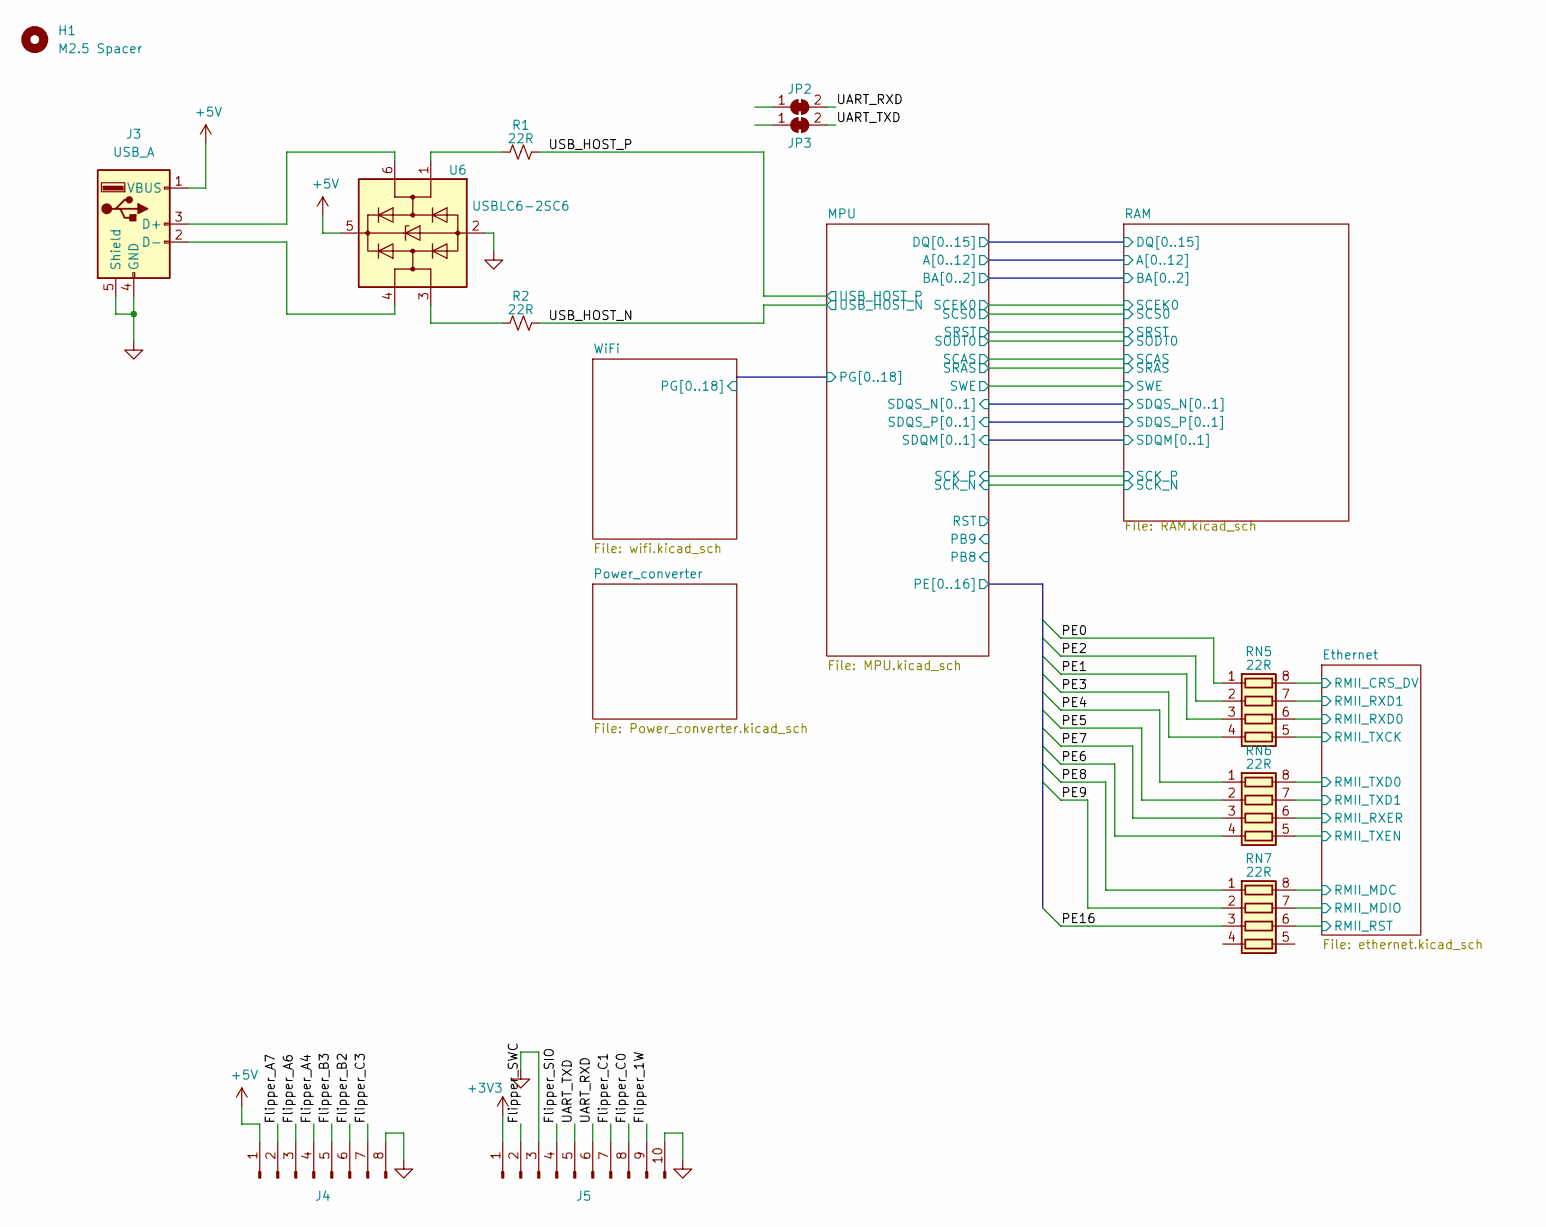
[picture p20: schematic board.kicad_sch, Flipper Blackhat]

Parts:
H1: M2.5 Spacer; 9774025151R; MPN 9774025151R
J3: USB_A; USB_A_Receptacle_GCT_USB1046; MPN USB1046-GF-0190-L-B-A
J4: Conn_01x08_Pin; PinHeader_1x08_P2.54mm_Horizontal; MPN PH1RB-08-UA
J5: Conn_01x10_Pin; PinHeader_1x10_P2.54mm_Horizontal; MPN PH1RB-10-UA
JP2, JP3: SolderJumper_2_Bridged; SolderJumper-2_P1.3mm_Bridged2Bar_RoundedPad1.0x1.5mm
R1, R2: 22R; R_0603_1608Metric; MPN RC0603FR-1322RL
RN5, RN6, RN7: 22R; R_Array_Convex_4x0402; MPN 4D02WGJ0220TCE
U6: USBLC6-2SC6; SOT-23-6; MPN USBLC6-2SC6

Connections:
+3V3: J5.1; also elsewhere on the board
+5V: J3.1 (VBUS), J4.1, U6.5 (VBUS); also elsewhere on the board
/Ethernet/RMII_CRS_DV: RN5.8 (R1.2); also elsewhere on the board
/Ethernet/RMII_MDC: RN7.8 (R1.2); also elsewhere on the board
/Ethernet/RMII_MDIO: RN7.7 (R2.2); also elsewhere on the board
/Ethernet/RMII_RXD0: RN5.6 (R3.2); also elsewhere on the board
/Ethernet/RMII_RXD1: RN5.7 (R2.2); also elsewhere on the board
/Ethernet/RMII_RXER: RN6.6 (R3.2); also elsewhere on the board
/Ethernet/RMII_TXCK: RN5.5 (R4.2); also elsewhere on the board
/Ethernet/RMII_TXD0: RN6.8 (R1.2); also elsewhere on the board
/Ethernet/RMII_TXD1: RN6.7 (R2.2); also elsewhere on the board
/Ethernet/RMII_TXEN: RN6.5 (R4.2); also elsewhere on the board
/Ethernet/RST: RN7.6 (R3.2); also elsewhere on the board
/Flipper_1W: J5.9
/Flipper_A4: J4.4
/Flipper_A6: J4.3
/Flipper_A7: J4.2
/Flipper_B2: J4.6
/Flipper_B3: J4.5
/Flipper_C0: J5.8
/Flipper_C1: J5.7
/Flipper_C3: J4.7
/Flipper_SIO: J5.4
/Flipper_SWC: J5.2
/MPU/PE0: RN5.1 (R1.1); also elsewhere on the board
/MPU/PE1: RN5.3 (R3.1); also elsewhere on the board
/MPU/PE2: RN5.2 (R2.1); also elsewhere on the board
/MPU/PE3: RN5.4 (R4.1); also elsewhere on the board
/MPU/PE4: RN6.1 (R1.1); also elsewhere on the board
/MPU/PE5: RN6.2 (R2.1); also elsewhere on the board
/MPU/PE6: RN6.4 (R4.1); also elsewhere on the board
/MPU/PE7: RN6.3 (R3.1); also elsewhere on the board
/MPU/PE8: RN7.1 (R1.1); also elsewhere on the board
/MPU/PE9: RN7.2 (R2.1); also elsewhere on the board
/MPU/PE16: RN7.3 (R3.1); also elsewhere on the board
/UART_RXD: J5.6, JP2.2 (B)
/UART_TXD: J5.5, JP3.2 (B)
/USB_HOST_N: R2.2; also elsewhere on the board
/USB_HOST_P: R1.2; also elsewhere on the board
GND: J3.4 (GND), J3.5 (Shield), J4.8, J5.3, J5.10, U6.2 (GND); also elsewhere on the board
unnamed: J3.3 (D+), U6.6 (I/O1)
unnamed: J3.2 (D-), U6.4 (I/O2)
unnamed: R1.1, U6.1 (I/O1)
unnamed: R2.1, U6.3 (I/O2)

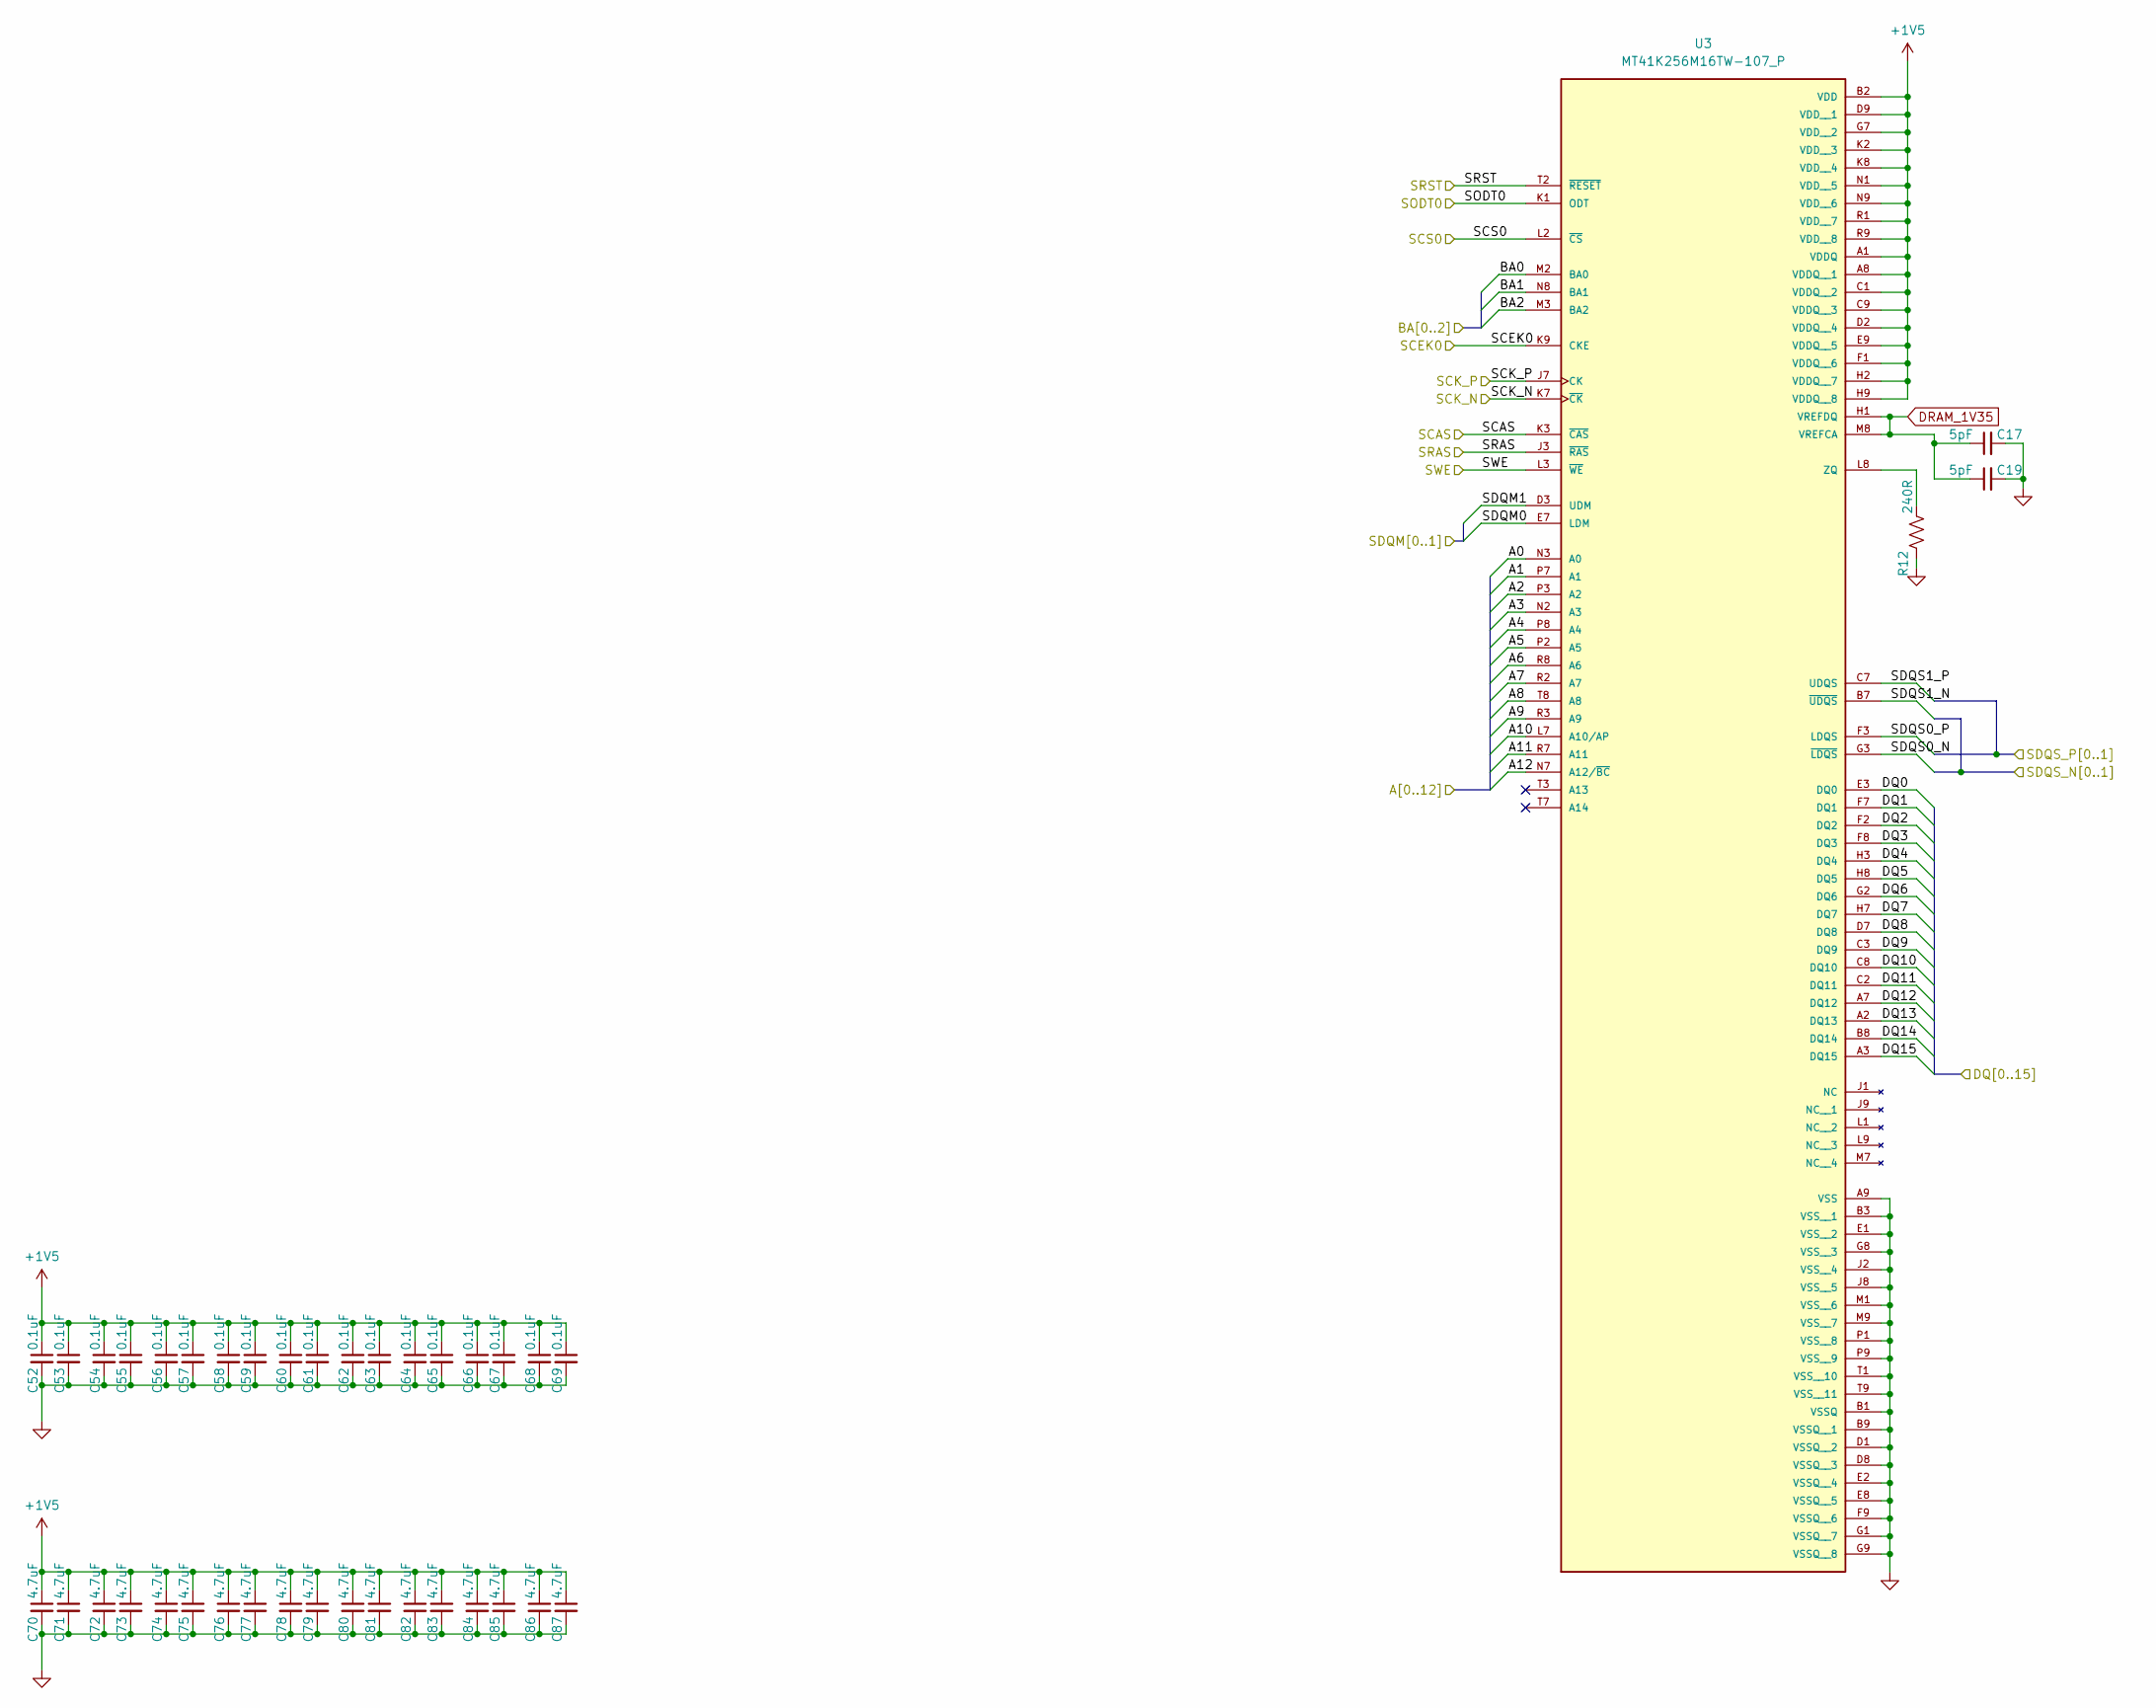
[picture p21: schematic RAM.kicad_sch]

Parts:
C17, C19: 5PF 50V C0G/NP0 0603; C_0603_1608Metric; MPN CL10C050CB81PNC
C52, C53, C54, C55, C56, C57, C58, C59, C60, C61, C62, C63, C64, C65, C66, C67, C68, C69: 16V 0.1uF X7R 0402; C_0402_1005Metric; MPN MLASE105SB7104KFNA01
C70, C71, C72, C73, C74, C75, C76, C77, C78, C79, C80, C81, C82, C83, C84, C85, C86, C87: 4.7 uF 16V 0805 X7R; C_0402_1005Metric; MPN C0805C475K4RACAUTO
R12: 240R; R_0603_1608Metric; MPN CRCW0603240RFKEAC
U3: MT41K256M16TW-107_P; BGA96C80P9X16_1400X800X120; PARTREV P

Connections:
+1V5: C52.1, C53.1, C54.1, C55.1, C56.1, C57.1, C58.1, C59.1, C60.1, C61.1, C62.1, C63.1, C64.1, C65.1, C66.1, C67.1, C68.1, C69.1, C70.1, C71.1, C72.1, C73.1, C74.1, C75.1, C76.1, C77.1, C78.1, C79.1, C80.1, C81.1, C82.1, C83.1, C84.1, C85.1, C86.1, C87.1, U3.A1 (VDDQ), U3.A8 (VDDQ__1), U3.B2 (VDD), U3.C1 (VDDQ__2), U3.C9 (VDDQ__3), U3.D2 (VDDQ__4), U3.D9 (VDD__1), U3.E9 (VDDQ__5), U3.F1 (VDDQ__6), U3.G7 (VDD__2), U3.H2 (VDDQ__7), U3.H9 (VDDQ__8), U3.K2 (VDD__3), U3.K8 (VDD__4), U3.N1 (VDD__5), U3.N9 (VDD__6), U3.R1 (VDD__7), U3.R9 (VDD__8); also elsewhere on the board
/MPU/A0: U3.N3 (A0); also elsewhere on the board
/MPU/A1: U3.P7 (A1); also elsewhere on the board
/MPU/A2: U3.P3 (A2); also elsewhere on the board
/MPU/A3: U3.N2 (A3); also elsewhere on the board
/MPU/A4: U3.P8 (A4); also elsewhere on the board
/MPU/A5: U3.P2 (A5); also elsewhere on the board
/MPU/A6: U3.R8 (A6); also elsewhere on the board
/MPU/A7: U3.R2 (A7); also elsewhere on the board
/MPU/A8: U3.T8 (A8); also elsewhere on the board
/MPU/A9: U3.R3 (A9); also elsewhere on the board
/MPU/A10: U3.L7 (A10/AP); also elsewhere on the board
/MPU/A11: U3.R7 (A11); also elsewhere on the board
/MPU/A12: U3.N7 (A12/~BC); also elsewhere on the board
/MPU/BA0: U3.M2 (BA0); also elsewhere on the board
/MPU/BA1: U3.N8 (BA1); also elsewhere on the board
/MPU/BA2: U3.M3 (BA2); also elsewhere on the board
/MPU/DQ0: U3.E3 (DQ0); also elsewhere on the board
/MPU/DQ1: U3.F7 (DQ1); also elsewhere on the board
/MPU/DQ2: U3.F2 (DQ2); also elsewhere on the board
/MPU/DQ3: U3.F8 (DQ3); also elsewhere on the board
/MPU/DQ4: U3.H3 (DQ4); also elsewhere on the board
/MPU/DQ5: U3.H8 (DQ5); also elsewhere on the board
/MPU/DQ6: U3.G2 (DQ6); also elsewhere on the board
/MPU/DQ7: U3.H7 (DQ7); also elsewhere on the board
/MPU/DQ8: U3.D7 (DQ8); also elsewhere on the board
/MPU/DQ9: U3.C3 (DQ9); also elsewhere on the board
/MPU/DQ10: U3.C8 (DQ10); also elsewhere on the board
/MPU/DQ11: U3.C2 (DQ11); also elsewhere on the board
/MPU/DQ12: U3.A7 (DQ12); also elsewhere on the board
/MPU/DQ13: U3.A2 (DQ13); also elsewhere on the board
/MPU/DQ14: U3.B8 (DQ14); also elsewhere on the board
/MPU/DQ15: U3.A3 (DQ15); also elsewhere on the board
/MPU/SCAS: U3.K3 (~CAS); also elsewhere on the board
/MPU/SCEK0: U3.K9 (CKE); also elsewhere on the board
/MPU/SCK_N: U3.K7 (~CK); also elsewhere on the board
/MPU/SCK_P: U3.J7 (CK); also elsewhere on the board
/MPU/SCS0: U3.L2 (~CS); also elsewhere on the board
/MPU/SDQM0: U3.E7 (LDM); also elsewhere on the board
/MPU/SDQM1: U3.D3 (UDM); also elsewhere on the board
/MPU/SODT0: U3.K1 (ODT); also elsewhere on the board
/MPU/SRAS: U3.J3 (~RAS); also elsewhere on the board
/MPU/SRST: U3.T2 (~RESET); also elsewhere on the board
/MPU/SWE: U3.L3 (~WE); also elsewhere on the board
/RAM/SDQS0_N: U3.G3 (~LDQS)
/RAM/SDQS0_P: U3.F3 (LDQS)
/RAM/SDQS1_N: U3.B7 (~UDQS)
/RAM/SDQS1_P: U3.C7 (UDQS)
DRAM_1V35: C17.1, C19.1, U3.H1 (VREFDQ), U3.M8 (VREFCA); also elsewhere on the board
GND: C17.2, C19.2, C52.2, C53.2, C54.2, C55.2, C56.2, C57.2, C58.2, C59.2, C60.2, C61.2, C62.2, C63.2, C64.2, C65.2, C66.2, C67.2, C68.2, C69.2, C70.2, C71.2, C72.2, C73.2, C74.2, C75.2, C76.2, C77.2, C78.2, C79.2, C80.2, C81.2, C82.2, C83.2, C84.2, C85.2, C86.2, C87.2, R12.1, U3.A9 (VSS), U3.B1 (VSSQ), U3.B3 (VSS__1), U3.B9 (VSSQ__1), U3.D1 (VSSQ__2), U3.D8 (VSSQ__3), U3.E1 (VSS__2), U3.E2 (VSSQ__4), U3.E8 (VSSQ__5), U3.F9 (VSSQ__6), U3.G1 (VSSQ__7), U3.G8 (VSS__3), U3.G9 (VSSQ__8), U3.J2 (VSS__4), U3.J8 (VSS__5), U3.M1 (VSS__6), U3.M9 (VSS__7), U3.P1 (VSS__8), U3.P9 (VSS__9), U3.T1 (VSS__10), U3.T9 (VSS__11); also elsewhere on the board
unnamed: R12.2, U3.L8 (ZQ)

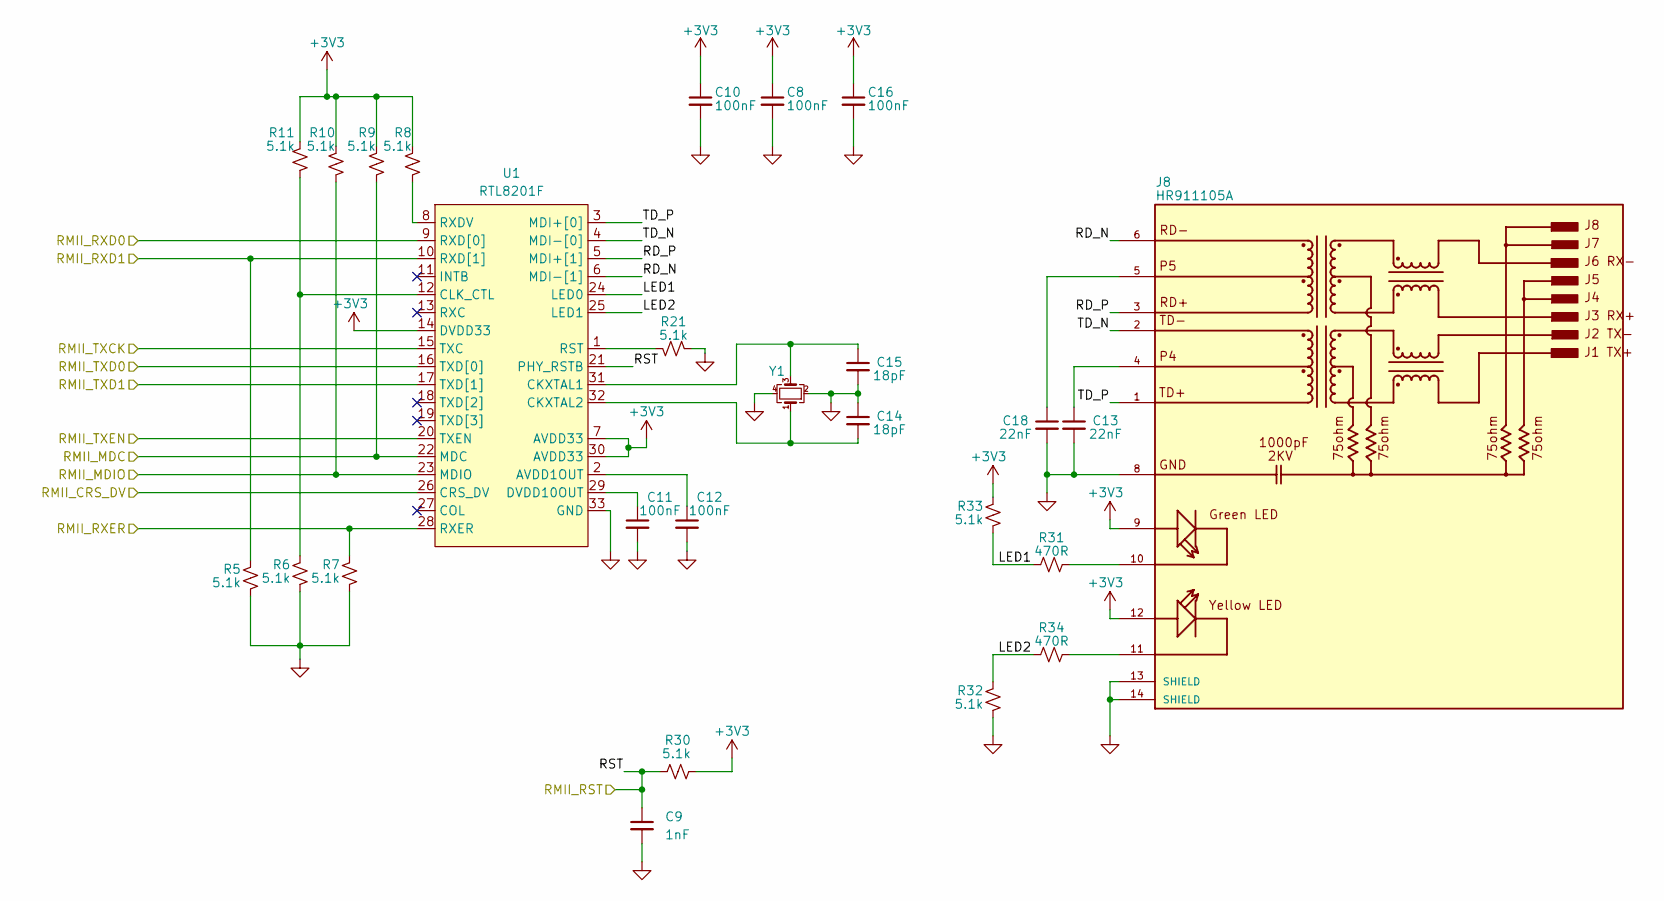
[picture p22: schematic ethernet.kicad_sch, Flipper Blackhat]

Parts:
C8, C10, C11, C12, C16: 100nF; C_0603_1608Metric; MPN CC0603KRX7R7BB104
C9: 1nF; C_0603_1608Metric; MPN CC0603KRX7R7BB102
C13, C18: 22nF; C_0603_1608Metric; MPN CC0603KRX7R7BB223
C14, C15: 18pF; C_0603_1608Metric; MPN CC0603JPNPO9BN180
J8: HR911105A; HR911105a; MPN HR911105A
R5, R6, R7, R8, R9, R10, R11, R21, R30, R32, R33: 5.1k; R_0603_1608Metric; MPN RC0603FR-135K1L
R31, R34: 470R; R_0603_1608Metric; MPN RC0603FR-13470KL
U1: RTL8201F; QFN-32-1EP_5x5mm_P0.5mm_EP3.3x3.3mm; MPN RTL8201F
Y1: Crystal_GND24_Small; Crystal_SMD_3225-4Pin_3.2x2.5mm; MPN 7M25000033

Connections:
+3V3: C8.1, C10.1, C16.1, J8.9, J8.12, R8.2, R9.2, R10.2, R11.2, R30.1, R33.2, U1.7 (AVDD33), U1.14 (DVDD33), U1.30 (AVDD33); also elsewhere on the board
/Ethernet/LED1: R31.2, R33.1, U1.24 (LED0)
/Ethernet/LED2: R32.2, R34.2, U1.25 (LED1)
/Ethernet/RD_N: J8.6, U1.6 (MDI-[1])
/Ethernet/RD_P: J8.3, U1.5 (MDI+[1])
/Ethernet/RMII_CRS_DV: U1.26 (CRS_DV); also elsewhere on the board
/Ethernet/RMII_MDC: R9.1, U1.22 (MDC); also elsewhere on the board
/Ethernet/RMII_MDIO: R10.1, U1.23 (MDIO); also elsewhere on the board
/Ethernet/RMII_RXD0: U1.9 (RXD[0]); also elsewhere on the board
/Ethernet/RMII_RXD1: R5.2, U1.10 (RXD[1]); also elsewhere on the board
/Ethernet/RMII_RXER: R7.2, U1.28 (RXER); also elsewhere on the board
/Ethernet/RMII_TXCK: U1.15 (TXC); also elsewhere on the board
/Ethernet/RMII_TXD0: U1.16 (TXD[0]); also elsewhere on the board
/Ethernet/RMII_TXD1: U1.17 (TXD[1]); also elsewhere on the board
/Ethernet/RMII_TXEN: U1.20 (TXEN); also elsewhere on the board
/Ethernet/RST: C9.1, R30.2, U1.21 (PHY_RSTB); also elsewhere on the board
/Ethernet/TD_N: J8.2, U1.4 (MDI-[0])
/Ethernet/TD_P: J8.1, U1.3 (MDI+[0])
GND: C8.2, C9.2, C10.2, C11.2, C12.2, C13.2, C14.1, C15.2, C16.2, C18.2, J8.8, J8.13 (SHIELD), J8.14 (SHIELD), R5.1, R6.1, R7.1, R21.2, R32.1, U1.33 (GND), Y1.2, Y1.4; also elsewhere on the board
unnamed: C13.1, J8.4
unnamed: C18.1, J8.5
unnamed: J8.10, R31.1
unnamed: J8.11, R34.1
unnamed: C12.1, U1.2 (AVDD1OUT)
unnamed: C15.1, U1.31 (CKXTAL1), Y1.3
unnamed: C14.2, U1.32 (CKXTAL2), Y1.1
unnamed: R6.2, R11.1, U1.12 (CLK_CTL)
unnamed: C11.1, U1.29 (DVDD10OUT)
unnamed: R21.1, U1.1 (RST)
unnamed: R8.1, U1.8 (RXDV)

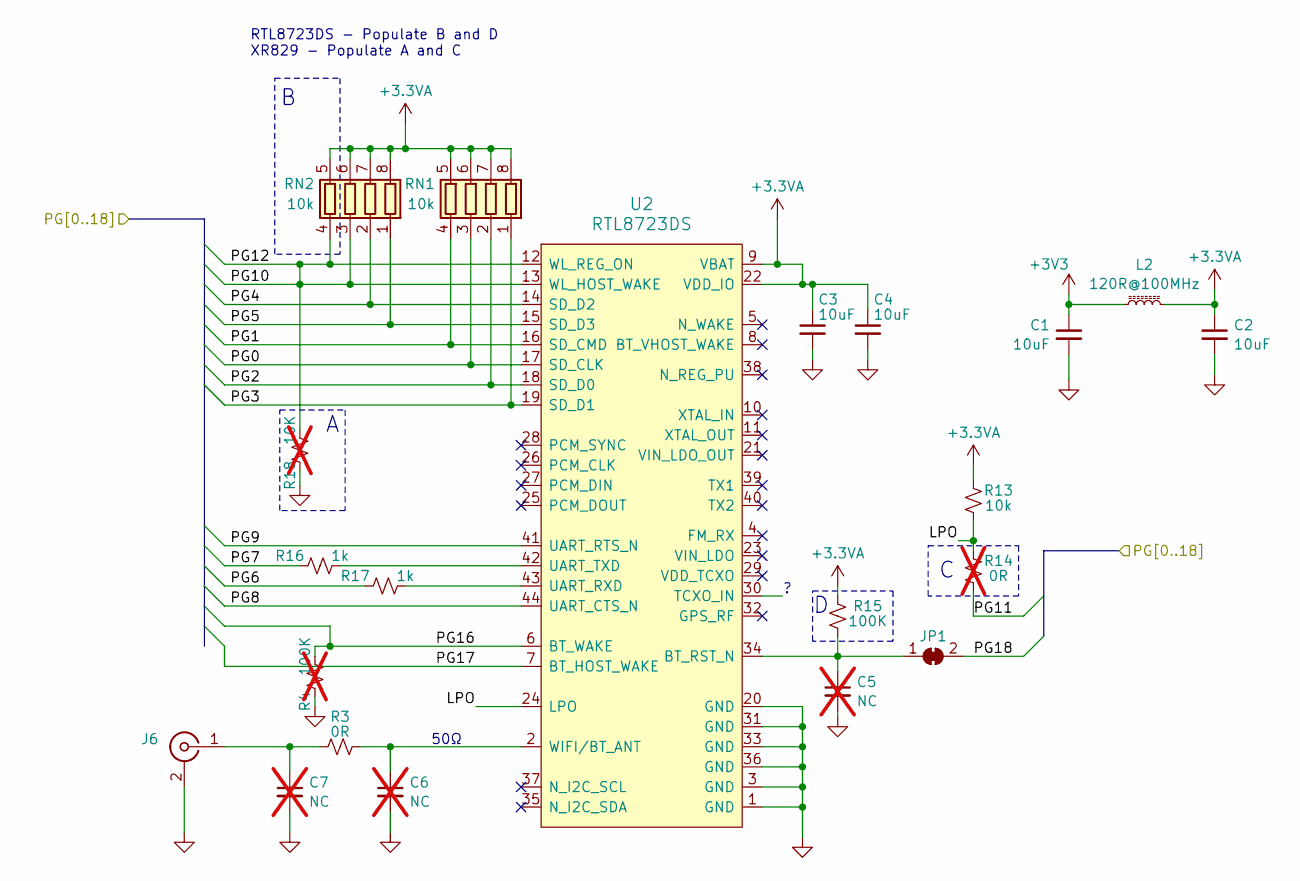
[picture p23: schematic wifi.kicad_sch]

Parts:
C1, C2, C3, C4: 10uF; C_0603_1608Metric; MPN LMK107BBJ106MALT
C5, C6, C7: NC; C_0603_1608Metric; not fitted
J6: Conn_Coaxial; SMA_Amphenol_901-143_Horizontal; MPN 901-143-6RFX
JP1: SolderJumper_2_Bridged; SolderJumper-2_P1.3mm_Bridged2Bar_RoundedPad1.0x1.5mm
L2: 120R@100MHz; R_0805_2012Metric; MPN MMZ2012R121AT000
R3: 0R; R_0603_1608Metric; MPN RC0603FR-130RL
R4: 100K; R_0603_1608Metric; not fitted
R13: 10k; R_0603_1608Metric; MPN RC0603FR-1310KL
R14: 0R; R_0603_1608Metric; not fitted
R15: 100K; R_0603_1608Metric; MPN RC0603FR-13100KL
R16, R17: 1k; R_0603_1608Metric; MPN RC0603FR-131KL
R18: 10K; R_0603_1608Metric; not fitted
RN1, RN2: 10k; R_Array_Convex_4x0402; MPN 4D02WGJ0103TCE
U2: RTL8723DS; RTL8723; MPN RTL8723DS

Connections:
+3.3VA: C2.1, C3.1, C4.1, L2.2, R13.2, R15.2, RN1.5 (R4.2), RN1.6 (R3.2), RN1.7 (R2.2), RN1.8 (R1.2), RN2.5 (R4.2), RN2.6 (R3.2), RN2.7 (R2.2), RN2.8 (R1.2), U2.9 (VBAT), U2.22 (VDD_IO)
+3V3: C1.1, L2.1; also elsewhere on the board
/WiFi/LPO: R13.1, R14.2, U2.24 (LPO)
/WiFi/PG0: RN1.3 (R3.1), U2.17 (SD_CLK)
/WiFi/PG1: RN1.4 (R4.1), U2.16 (SD_CMD)
/WiFi/PG2: RN1.2 (R2.1), U2.18 (SD_D0)
/WiFi/PG3: RN1.1 (R1.1), U2.19 (SD_D1)
/WiFi/PG4: RN2.2 (R2.1), U2.14 (SD_D2)
/WiFi/PG5: RN2.1 (R1.1), U2.15 (SD_D3)
/WiFi/PG6: R17.1
/WiFi/PG7: R16.1
/WiFi/PG8: U2.44 (UART_CTS_N)
/WiFi/PG9: U2.41 (UART_RTS_N)
/WiFi/PG10: R18.2, RN2.3 (R3.1), RN2.4 (R4.1), U2.12 (WL_REG_ON), U2.13 (WL_HOST_WAKE)
/WiFi/PG11: R14.1
/WiFi/PG16: R4.2, U2.6 (BT_WAKE)
/WiFi/PG17: U2.7 (BT_HOST_WAKE)
/WiFi/PG18: JP1.2 (B)
GND: C1.2, C2.2, C3.2, C4.2, C5.2, C6.2, C7.2, J6.2 (Ext), R4.1, R18.1, U2.1 (GND), U2.3 (GND), U2.20 (GND), U2.31 (GND), U2.33 (GND), U2.36 (GND); also elsewhere on the board
unnamed: C7.1, J6.1 (In), R3.1
unnamed: C5.1, JP1.1 (A), R15.1, U2.34 (BT_RST_N)
unnamed: R17.2, U2.43 (UART_RXD)
unnamed: R16.2, U2.42 (UART_TXD)
unnamed: C6.1, R3.2, U2.2 (WIFI/BT_ANT)

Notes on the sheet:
RTL8723DS - Populate B and D XR829 - Populate A and C
50Ω

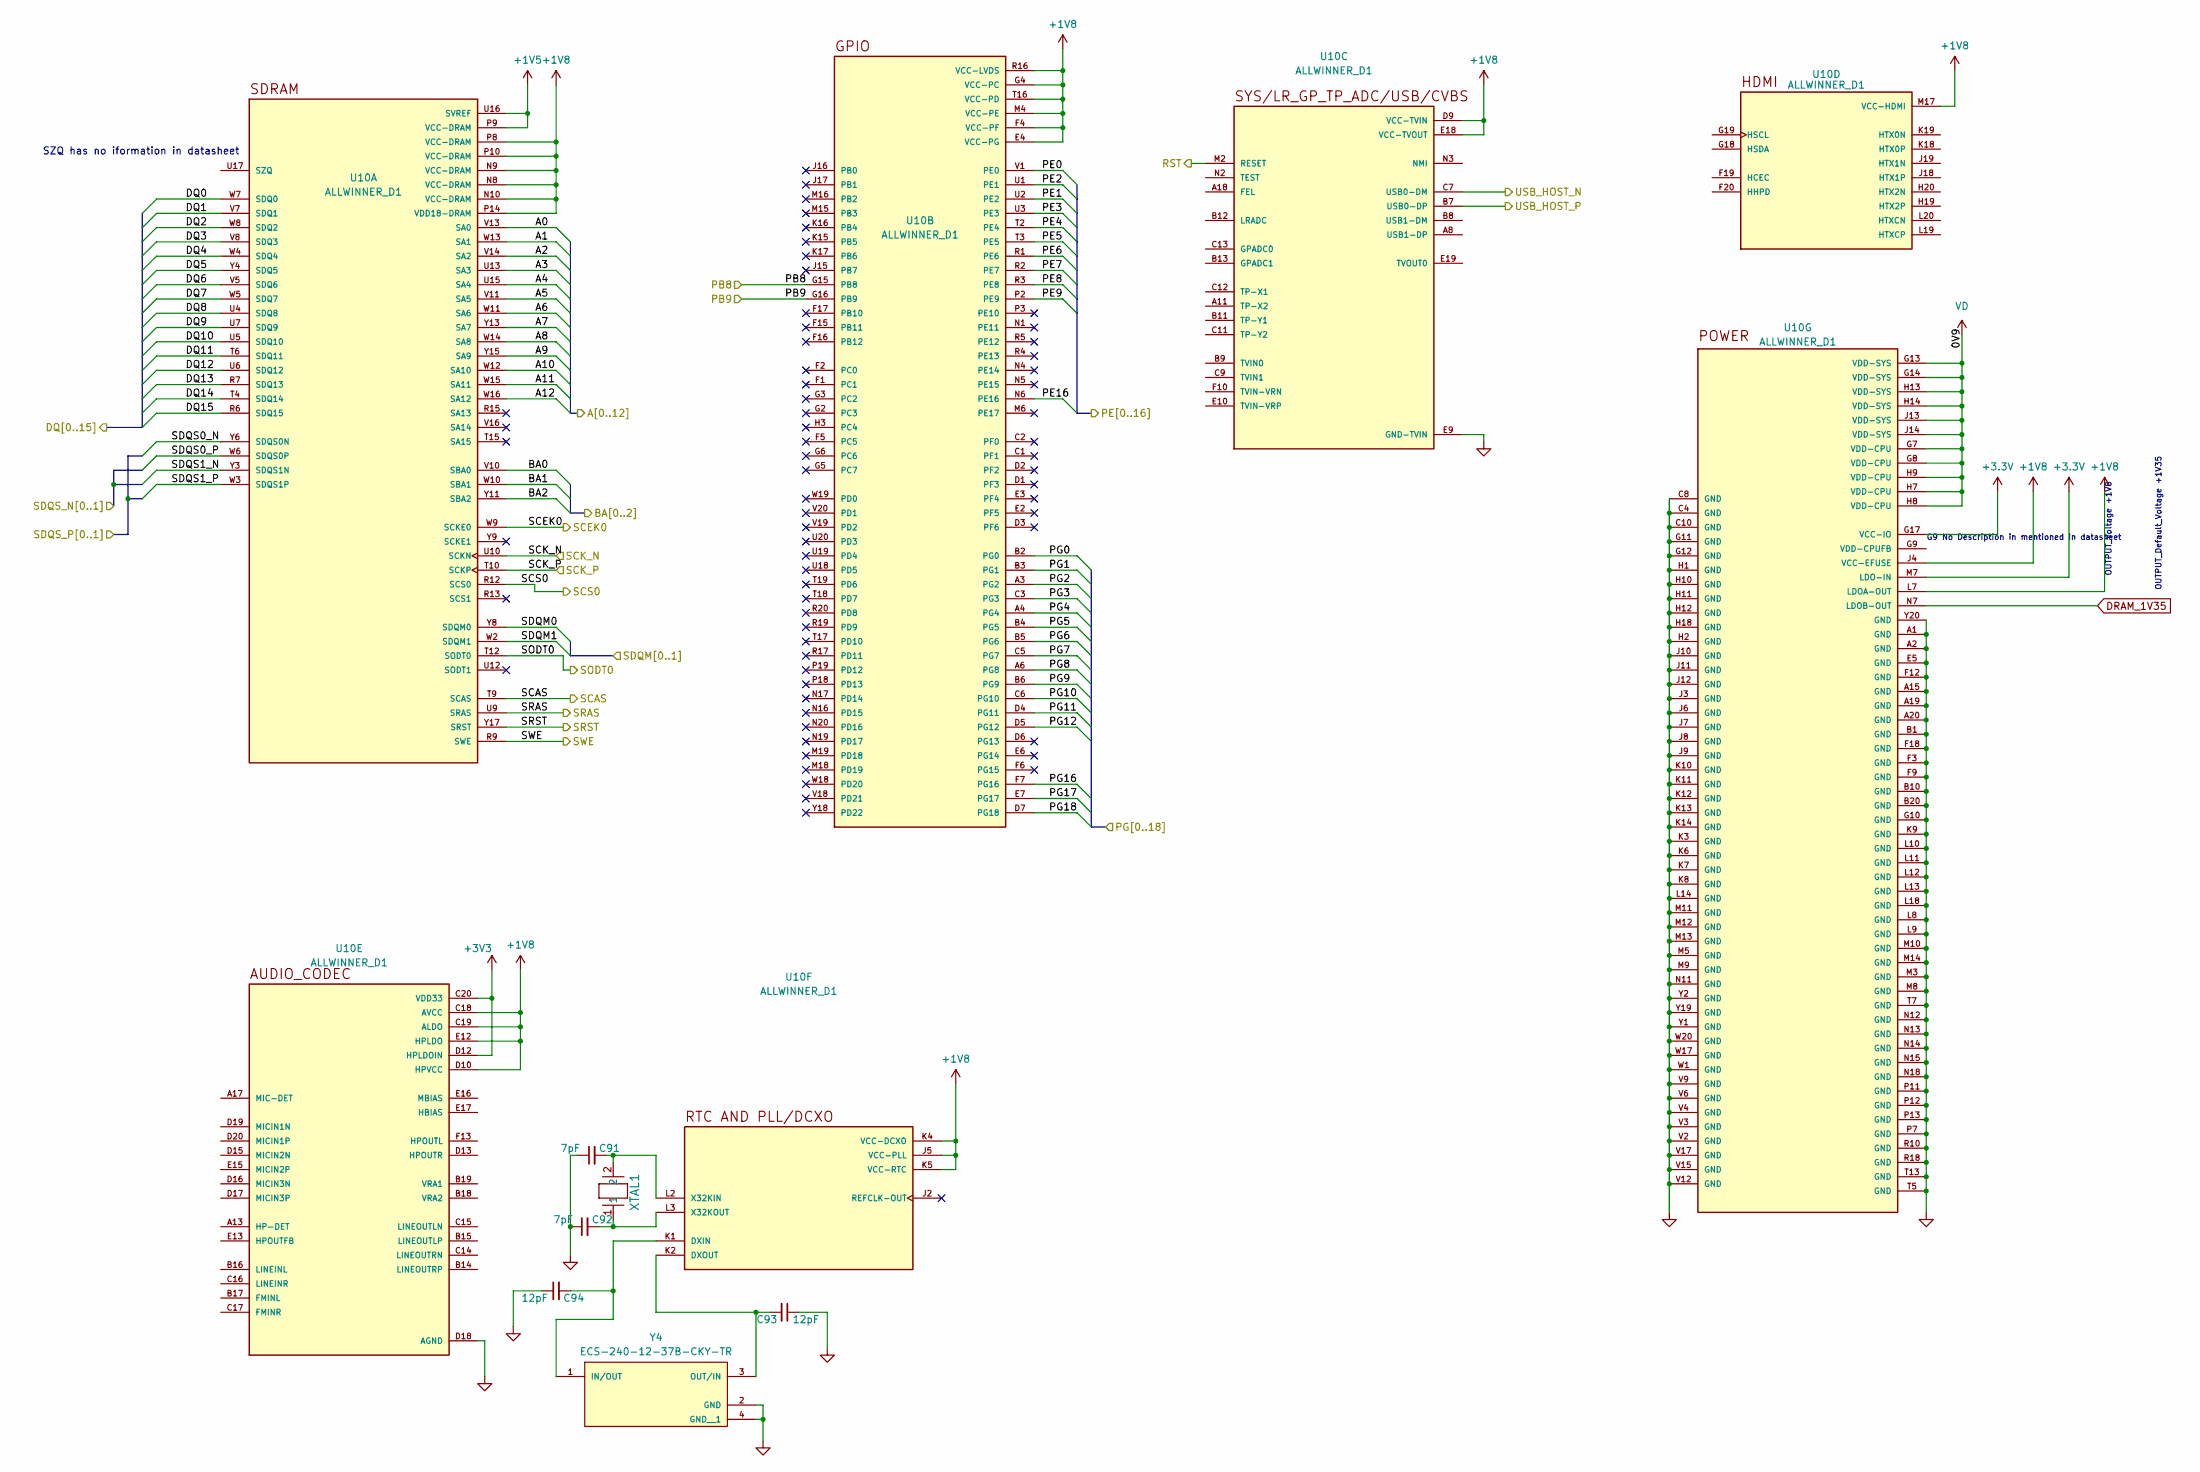
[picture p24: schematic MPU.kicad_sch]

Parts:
C91, C92: 7PF 50V C0G/NP0 0603; C_0402_1005Metric; MPN CL10C070CB8NNNC
C93, C94: 12PF 50V C0G/NP0; C_0402_1005Metric; MPN GJM1555C1H120FB01D
U10: ALLWINNER_D1; BGA337C65P20X20_1300X1300X133
XTAL1: SC32S-7PF20PPM; Crystal_SMD_TXC_7A-2Pin_5x3.2mm
Y4: ECS-240-12-37B-CKY-TR; XTAL_ECS-240-12-37B-CKY-TR

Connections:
+1V5: U10.P9 (VCC-DRAM), U10.U16 (SVREF); also elsewhere on the board
+1V8: U10.C18 (AVCC), U10.C19 (ALDO), U10.D9 (VCC-TVIN), U10.D10 (HPVCC), U10.E4 (VCC-PG), U10.E12 (HPLDO), U10.E18 (VCC-TVOUT), U10.F4 (VCC-PF), U10.G4 (VCC-PC), U10.J4 (VCC-EFUSE), U10.J5 (VCC-PLL), U10.K4 (VCC-DCXO), U10.K5 (VCC-RTC), U10.L7 (LDOA-OUT), U10.M4 (VCC-PE), U10.M17 (VCC-HDMI), U10.N8 (VCC-DRAM), U10.N9 (VCC-DRAM), U10.N10 (VCC-DRAM), U10.P8 (VCC-DRAM), U10.P10 (VCC-DRAM), U10.P14 (VDD18-DRAM), U10.R16 (VCC-LVDS), U10.T16 (VCC-PD)
+3.3V: U10.G17 (VCC-IO), U10.M7 (LDO-IN); also elsewhere on the board
+3V3: U10.C20 (VDD33), U10.D12 (HPLDOIN); also elsewhere on the board
/MPU/A0: U10.V13 (SA0); also elsewhere on the board
/MPU/A1: U10.W13 (SA1); also elsewhere on the board
/MPU/A2: U10.V14 (SA2); also elsewhere on the board
/MPU/A3: U10.U13 (SA3); also elsewhere on the board
/MPU/A4: U10.U15 (SA4); also elsewhere on the board
/MPU/A5: U10.V11 (SA5); also elsewhere on the board
/MPU/A6: U10.W11 (SA6); also elsewhere on the board
/MPU/A7: U10.Y13 (SA7); also elsewhere on the board
/MPU/A8: U10.W14 (SA8); also elsewhere on the board
/MPU/A9: U10.Y15 (SA9); also elsewhere on the board
/MPU/A10: U10.W12 (SA10); also elsewhere on the board
/MPU/A11: U10.W15 (SA11); also elsewhere on the board
/MPU/A12: U10.W16 (SA12); also elsewhere on the board
/MPU/BA0: U10.V10 (SBA0); also elsewhere on the board
/MPU/BA1: U10.W10 (SBA1); also elsewhere on the board
/MPU/BA2: U10.Y11 (SBA2); also elsewhere on the board
/MPU/DQ0: U10.W7 (SDQ0); also elsewhere on the board
/MPU/DQ1: U10.V7 (SDQ1); also elsewhere on the board
/MPU/DQ2: U10.W8 (SDQ2); also elsewhere on the board
/MPU/DQ3: U10.V8 (SDQ3); also elsewhere on the board
/MPU/DQ4: U10.W4 (SDQ4); also elsewhere on the board
/MPU/DQ5: U10.Y4 (SDQ5); also elsewhere on the board
/MPU/DQ6: U10.V5 (SDQ6); also elsewhere on the board
/MPU/DQ7: U10.W5 (SDQ7); also elsewhere on the board
/MPU/DQ8: U10.U4 (SDQ8); also elsewhere on the board
/MPU/DQ9: U10.U7 (SDQ9); also elsewhere on the board
/MPU/DQ10: U10.U5 (SDQ10); also elsewhere on the board
/MPU/DQ11: U10.T6 (SDQ11); also elsewhere on the board
/MPU/DQ12: U10.U6 (SDQ12); also elsewhere on the board
/MPU/DQ13: U10.R7 (SDQ13); also elsewhere on the board
/MPU/DQ14: U10.T4 (SDQ14); also elsewhere on the board
/MPU/DQ15: U10.R6 (SDQ15); also elsewhere on the board
/MPU/PB8: U10.G15 (PB8)
/MPU/PB9: U10.G16 (PB9)
/MPU/PE0: U10.V1 (PE0); also elsewhere on the board
/MPU/PE1: U10.U2 (PE2); also elsewhere on the board
/MPU/PE2: U10.U1 (PE1); also elsewhere on the board
/MPU/PE3: U10.U3 (PE3); also elsewhere on the board
/MPU/PE4: U10.T2 (PE4); also elsewhere on the board
/MPU/PE5: U10.T3 (PE5); also elsewhere on the board
/MPU/PE6: U10.R1 (PE6); also elsewhere on the board
/MPU/PE7: U10.R2 (PE7); also elsewhere on the board
/MPU/PE8: U10.R3 (PE8); also elsewhere on the board
/MPU/PE9: U10.P2 (PE9); also elsewhere on the board
/MPU/PE16: U10.N6 (PE16); also elsewhere on the board
/MPU/PG0: U10.B2 (PG0)
/MPU/PG1: U10.B3 (PG1)
/MPU/PG2: U10.A3 (PG2)
/MPU/PG3: U10.C3 (PG3)
/MPU/PG4: U10.A4 (PG4)
/MPU/PG5: U10.B4 (PG5)
/MPU/PG6: U10.B5 (PG6)
/MPU/PG7: U10.C5 (PG7)
/MPU/PG8: U10.A6 (PG8)
/MPU/PG9: U10.B6 (PG9)
/MPU/PG10: U10.C6 (PG10)
/MPU/PG11: U10.D4 (PG11)
/MPU/PG12: U10.D5 (PG12)
/MPU/PG16: U10.F7 (PG16)
/MPU/PG17: U10.E7 (PG17)
/MPU/PG18: U10.D7 (PG18)
/MPU/RST: U10.M2 (RESET)
/MPU/SCAS: U10.T9 (SCAS); also elsewhere on the board
/MPU/SCEK0: U10.W9 (SCKE0); also elsewhere on the board
/MPU/SCK_N: U10.U10 (SCKN); also elsewhere on the board
/MPU/SCK_P: U10.T10 (SCKP); also elsewhere on the board
/MPU/SCS0: U10.R12 (SCS0); also elsewhere on the board
/MPU/SDQM0: U10.Y8 (SDQM0); also elsewhere on the board
/MPU/SDQM1: U10.W2 (SDQM1); also elsewhere on the board
/MPU/SDQS0_N: U10.Y6 (SDQS0N)
/MPU/SDQS0_P: U10.W6 (SDQS0P)
/MPU/SDQS1_N: U10.Y3 (SDQS1N)
/MPU/SDQS1_P: U10.W3 (SDQS1P)
/MPU/SODT0: U10.T12 (SODT0); also elsewhere on the board
/MPU/SRAS: U10.U9 (SRAS); also elsewhere on the board
/MPU/SRST: U10.Y17 (SRST); also elsewhere on the board
/MPU/SWE: U10.R9 (SWE); also elsewhere on the board
/USB_HOST_N: U10.C7 (USB0-DM); also elsewhere on the board
/USB_HOST_P: U10.B7 (USB0-DP); also elsewhere on the board
DRAM_1V35: U10.N7 (LDOB-OUT); also elsewhere on the board
GND: C91.1, C92.1, C93.1, C94.1, U10.A1 (GND), U10.A2 (GND), U10.A15 (GND), U10.A19 (GND), U10.A20 (GND), U10.B1 (GND), U10.B10 (GND), U10.B20 (GND), U10.C4 (GND), U10.C8 (GND), U10.C10 (GND), U10.D18 (AGND), U10.E5 (GND), U10.E9 (GND-TVIN), U10.F3 (GND), U10.F9 (GND), U10.F12 (GND), U10.F18 (GND), U10.G10 (GND), U10.G11 (GND), U10.G12 (GND), U10.H1 (GND), U10.H2 (GND), U10.H10 (GND), U10.H11 (GND), U10.H12 (GND), U10.H18 (GND), U10.J3 (GND), U10.J6 (GND), U10.J7 (GND), U10.J8 (GND), U10.J9 (GND), U10.J10 (GND), U10.J11 (GND), U10.J12 (GND), U10.K3 (GND), U10.K6 (GND), U10.K7 (GND), U10.K8 (GND), U10.K9 (GND), U10.K10 (GND), U10.K11 (GND), U10.K12 (GND), U10.K13 (GND), U10.K14 (GND), U10.L8 (GND), U10.L9 (GND), U10.L10 (GND), U10.L11 (GND), U10.L12 (GND), U10.L13 (GND), U10.L14 (GND), U10.L18 (GND), U10.M3 (GND), U10.M5 (GND), U10.M8 (GND), U10.M9 (GND), U10.M10 (GND), U10.M11 (GND), U10.M12 (GND), U10.M13 (GND), U10.M14 (GND), U10.N11 (GND), U10.N12 (GND), U10.N13 (GND), U10.N14 (GND), U10.N15 (GND), U10.N18 (GND), U10.P7 (GND), U10.P11 (GND), U10.P12 (GND), U10.P13 (GND), U10.R10 (GND), U10.R18 (GND), U10.T5 (GND), U10.T7 (GND), U10.T13 (GND), U10.V2 (GND), U10.V3 (GND), U10.V4 (GND), U10.V6 (GND), U10.V9 (GND), U10.V12 (GND), U10.V15 (GND), U10.V17 (GND), U10.W1 (GND), U10.W17 (GND), U10.W20 (GND), U10.Y1 (GND), U10.Y2 (GND), U10.Y19 (GND), U10.Y20 (GND), Y4.2 (GND), Y4.4 (GND__1); also elsewhere on the board
unnamed: C94.2, U10.K1 (DXIN), Y4.1 (IN/OUT)
unnamed: C93.2, U10.K2 (DXOUT), Y4.3 (OUT/IN)
unnamed: C91.2, U10.L2 (X32KIN), XTAL1.2
unnamed: C92.2, U10.L3 (X32KOUT), XTAL1.1
VD: U10.G7 (VDD-CPU), U10.G8 (VDD-CPU), U10.G13 (VDD-SYS), U10.G14 (VDD-SYS), U10.H7 (VDD-CPU), U10.H8 (VDD-CPU), U10.H9 (VDD-CPU), U10.H13 (VDD-SYS), U10.H14 (VDD-SYS), U10.J13 (VDD-SYS), U10.J14 (VDD-SYS)

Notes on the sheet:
OUTPUT_Default_Voltage +1V35
OUTPUT_Voltage +1V8
SZQ has no iformation in datasheet
G9 No Description in mentioned in datasheet

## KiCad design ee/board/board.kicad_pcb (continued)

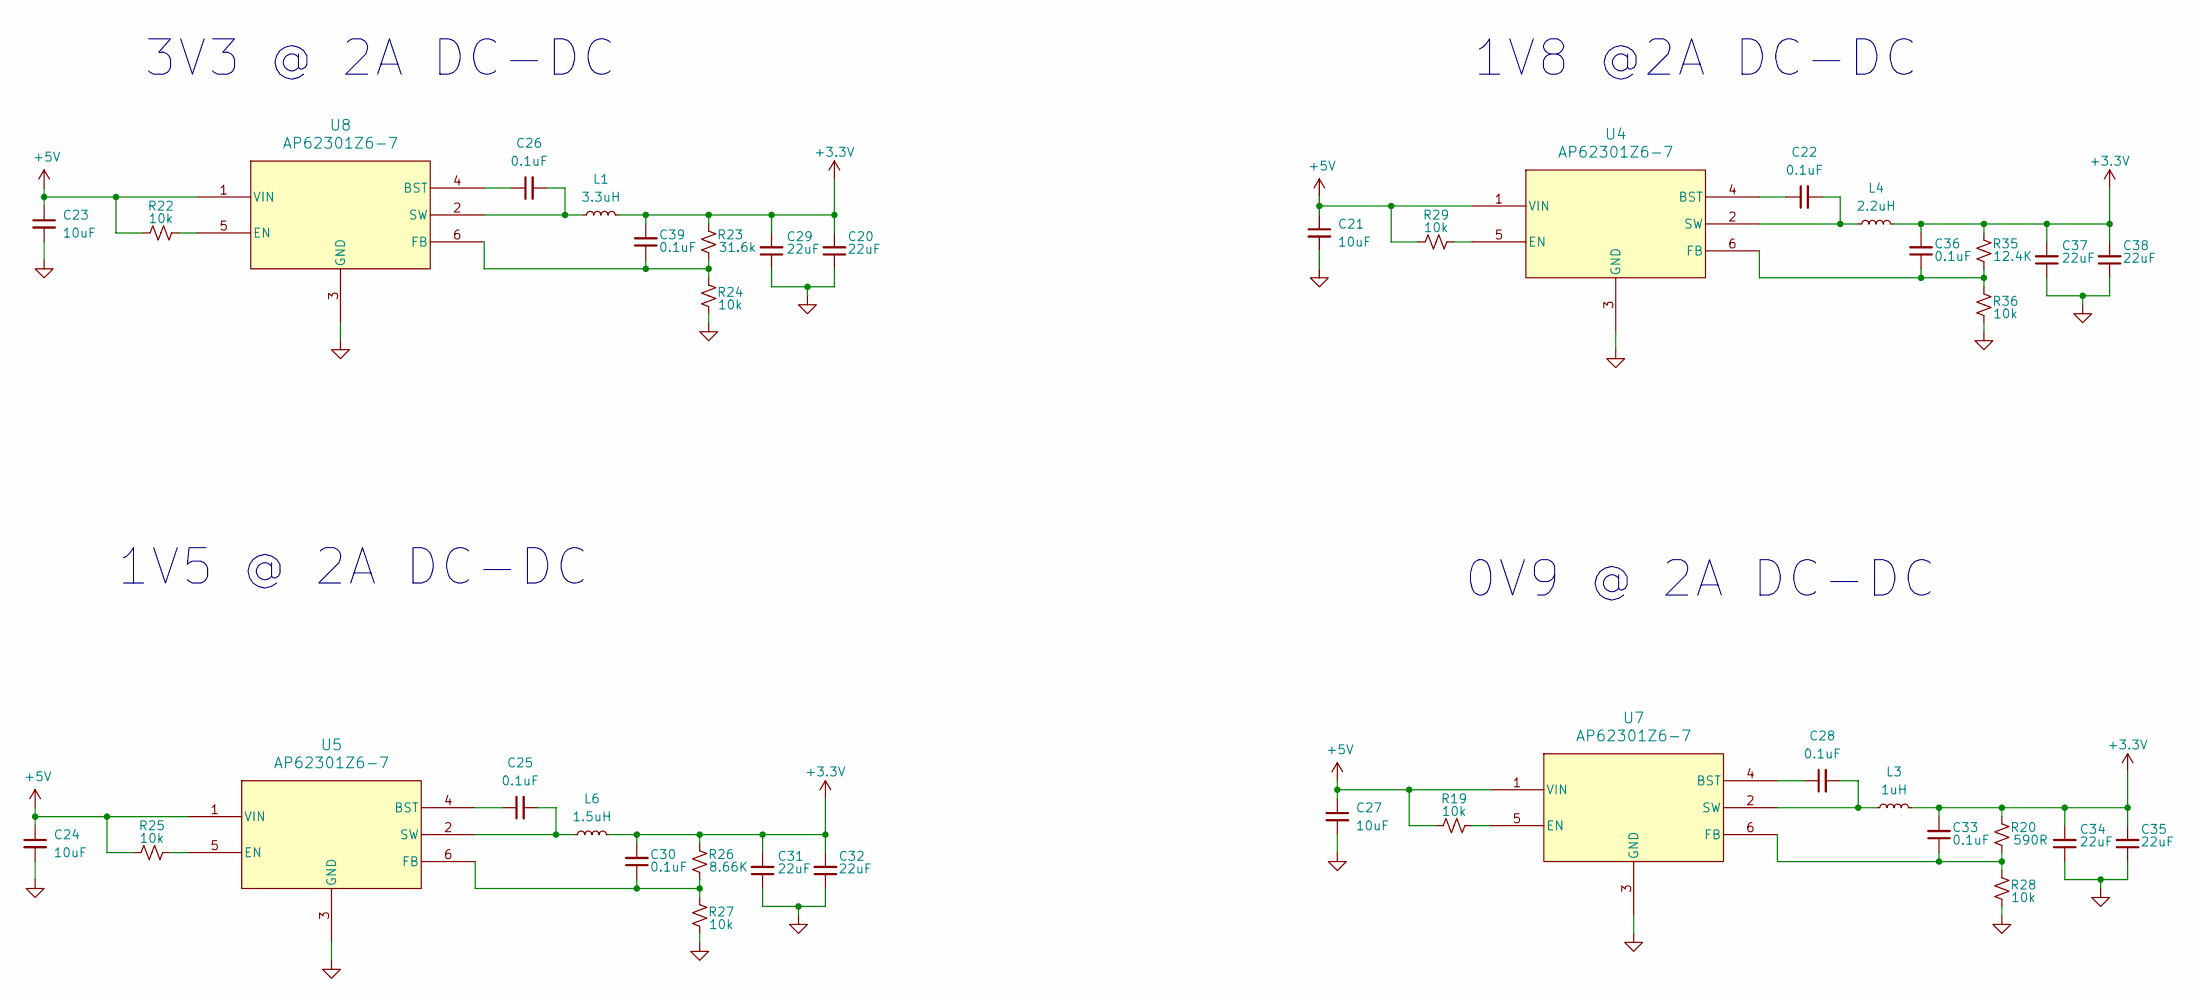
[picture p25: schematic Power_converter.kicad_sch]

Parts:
C20, C29, C31, C32, C34, C35, C37, C38: 22uF; C_0603_1608Metric
C21, C23, C24, C27: 10uF; C_0603_1608Metric
C22, C25, C26, C28: 0.1uF; C_0402_1005Metric
C30, C33, C36, C39: 0.1uF; C_0402_1005Metric; MPN MLASE105SB7104KFNA01
L1: 3.3uH; C_0402_1005Metric
L3: 1uH
L4: 2.2uH
L6: 1.5uH
R19, R22, R24, R25, R27, R28, R29, R36: 10k; R_0402_1005Metric
R20: 590R; R_0402_1005Metric
R23: 31.6k; R_0402_1005Metric
R26: 8.66K; R_0402_1005Metric
R35: 12.4K; R_0402_1005Metric
U4, U5, U7, U8: AP62301Z6-7; SOT563-Z6_1_DIO

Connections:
+3.3V: C20.2, C29.2, C30.2, C31.2, C32.2, C33.2, C34.2, C35.2, C36.2, C37.2, C38.2, C39.2, L1.2, L3.2, L4.2, L6.2, R20.2, R23.2, R26.2, R35.2; also elsewhere on the board
+5V: C21.1, C23.1, C24.1, C27.1, R19.1, R22.1, R25.1, R29.1, U4.1 (VIN), U5.1 (VIN), U7.1 (VIN), U8.1 (VIN); also elsewhere on the board
GND: C20.1, C21.2, C23.2, C24.2, C27.2, C29.1, C31.1, C32.1, C34.1, C35.1, C37.1, C38.1, R24.1, R27.1, R28.1, R36.1, U4.3 (GND), U5.3 (GND), U7.3 (GND), U8.3 (GND); also elsewhere on the board
unnamed: C22.1, U4.4 (BST)
unnamed: R29.2, U4.5 (EN)
unnamed: C36.1, R35.1, R36.2, U4.6 (FB)
unnamed: C22.2, L4.1, U4.2 (SW)
unnamed: C25.1, U5.4 (BST)
unnamed: R25.2, U5.5 (EN)
unnamed: C30.1, R26.1, R27.2, U5.6 (FB)
unnamed: C25.2, L6.1, U5.2 (SW)
unnamed: C28.1, U7.4 (BST)
unnamed: R19.2, U7.5 (EN)
unnamed: C33.1, R20.1, R28.2, U7.6 (FB)
unnamed: C28.2, L3.1, U7.2 (SW)
unnamed: C26.1, U8.4 (BST)
unnamed: R22.2, U8.5 (EN)
unnamed: C39.1, R23.1, R24.2, U8.6 (FB)
unnamed: C26.2, L1.1, U8.2 (SW)

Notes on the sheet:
0V9 @ 2A DC-DC
3V3 @ 2A DC-DC
1V5 @ 2A DC-DC
1V8 @2A DC-DC

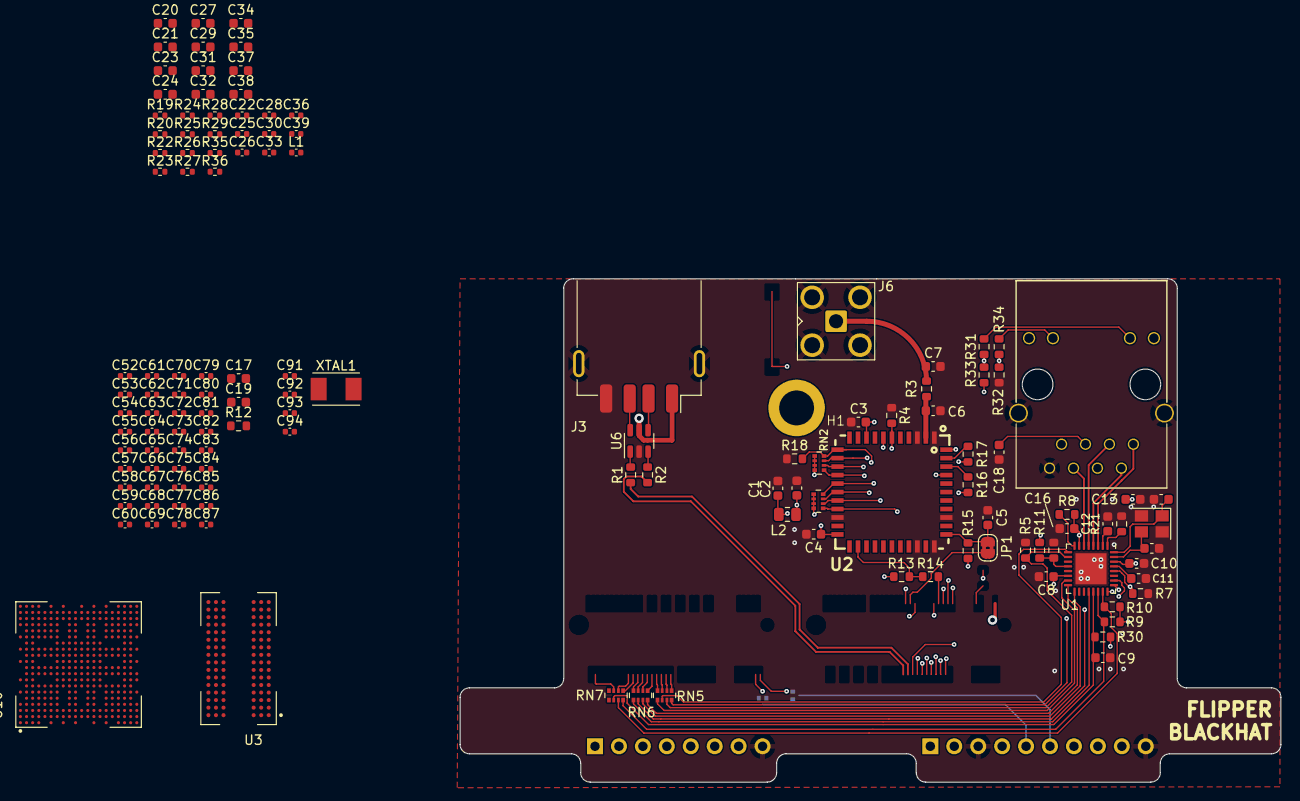
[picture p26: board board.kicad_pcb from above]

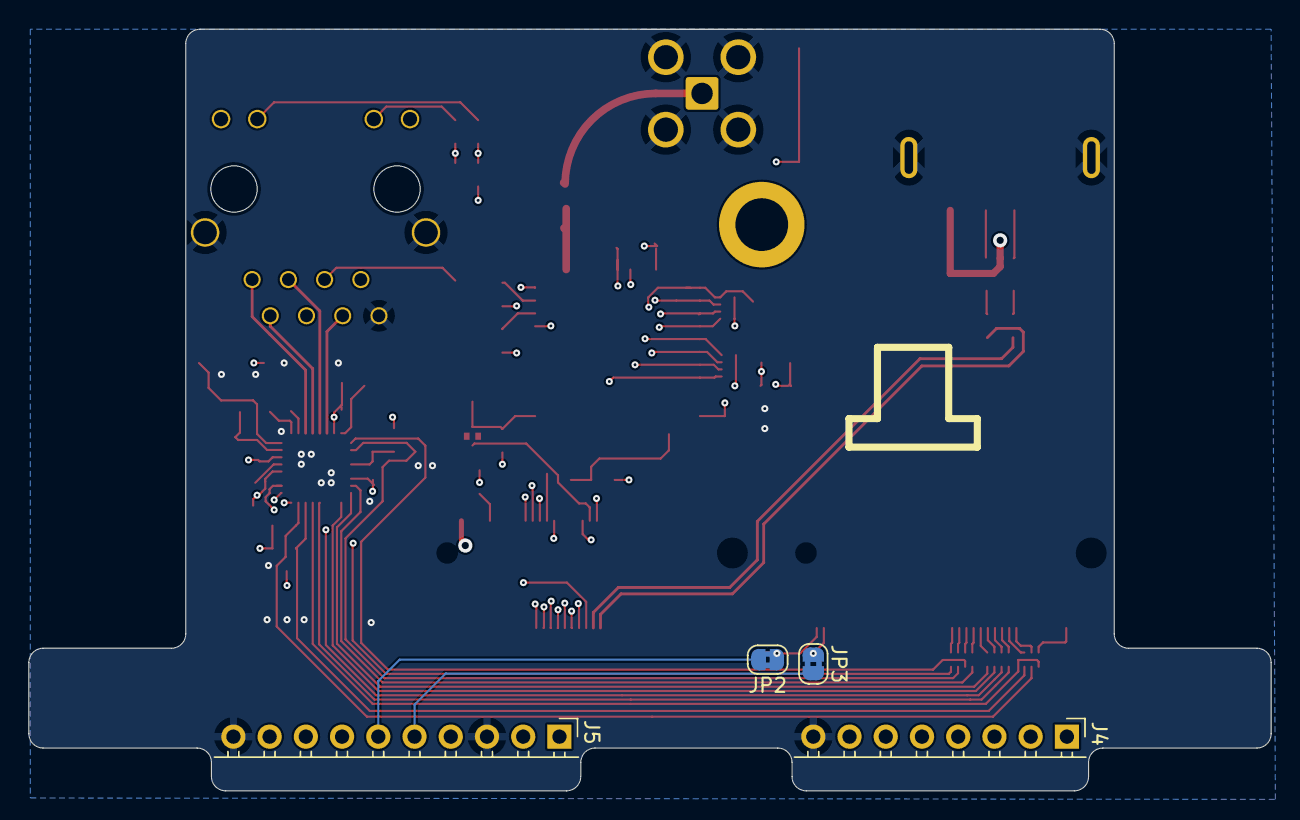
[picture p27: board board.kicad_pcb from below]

Board: 4 copper layers, 87.1 x 53.4 mm, 138 parts (4 on the bottom side), 123 nets.

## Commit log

2023-11-09 Initial commit.
    [676432911.stp, 732512120.stp, DM3AT-SF-PEJM5.stp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]
2023-11-27 Dropped in the M.2 connectors.
    [board.kicad_pcb, board.kicad_sch]
2023-11-29 Added in module
    [board.kicad_pcb, board.kicad_sch]
2023-11-29 Added the wifi module
    [board.kicad_sch]
2023-11-29 Added new wifi module
    [board.kicad_sch]
2024-01-04 Schematic mostly finished.
    [board.kicad_pcb, board.kicad_sch, ethernet.kicad_sch]
2024-01-04 Moved some of the local library stuff into the submodule.
    [board.kicad_pcb, board.kicad_sch]
2024-01-04 Moved everything else from the local library into the submodule.
    [board.kicad_pcb]
2024-01-06 Nearly finished routing.
    [board.kicad_pcb, board.kicad_sch, ethernet.kicad_sch]
2024-01-09 Finished R1
    [board.kicad_pcb, board.kicad_sch, ethernet.kicad_sch]
2024-01-16 Changed inductor side in R0.1 to fit the part number.
    [board-B_Cu.gbr, board-B_Mask.gbr, board-B_Paste.gbr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]
2024-05-06 Moved to a chip scale
    [MPU.kicad_sch, Power_converter.kicad_sch, RAM.kicad_sch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]
2024-05-10 Added the footprints into the design.
    [MPU.kicad_sch, Power_converter.kicad_sch, RAM.kicad_sch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]
2024-05-10 Leftover stuff
    [board.kicad_pcb]
